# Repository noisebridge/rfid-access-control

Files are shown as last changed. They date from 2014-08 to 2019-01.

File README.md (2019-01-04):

RFID access control
-------------------



Access control system used within the [Noisebridge] hacker space.

   - RFID door terminal
      * [Firmware](software/firmware/README.md)
      * [PCB](hardware/terminal/README.md)
      * [3D printed case](hardware/terminal-case/README.md)
   - [Multi RS232 serial interface with RJ45](hardware/multi-interface/README.md)
   - [Earl: Central access control software](software/earl/README.md)

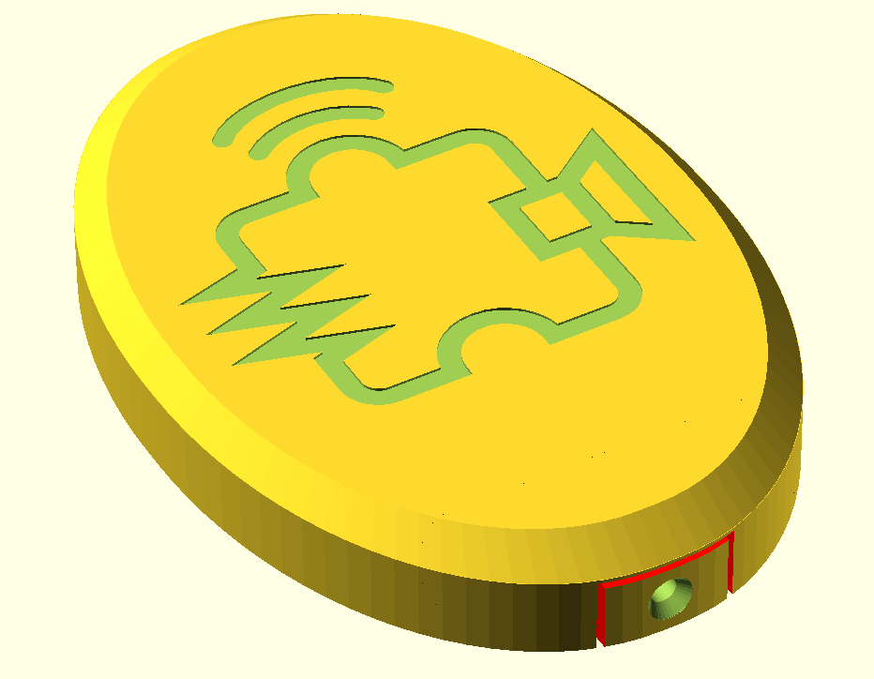
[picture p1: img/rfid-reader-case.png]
RFID reader


[case-image]: https://github.com/hzeller/rfid-access-control/raw/master/img/rfid-reader-case.png
[Noisebridge]: https://noisebridge.net/

## License

All code and PCB designs are released under the GNU General Public License V2, found in LICENSE

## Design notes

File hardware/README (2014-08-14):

Case
   - a case to mount the RFID reader on the wall.

Boards
  - terminal board with RFID-RC522, providing a serial interface and potentially
    local switching
  - interface board on 'server' side, interfacing the Raspberry Pi or Beaglebone
    with the physical world of serial interfaces an relay switching.

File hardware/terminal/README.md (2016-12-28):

Terminal PCB
============

The Access terminal mounted at the outside of the door. Typically connecting the
RFID reader (via SPI interface), but also a 4x3 keypad (or just simple door-bell
button) and an LCD can be connected. If wanted, even an electric strike via
some external H-bridge.

This is based on an Atmega8 because I had a bunch lying around, but the DIL
version is bulky and ideally, I'd like to have a bit more IO pins, such as
for a 4th row of the keypad or separate LED outputs; future versions might
change to atmega168 (currently the best Atmel-IO bang for the buck).

This board provides the necessary breakouts to connect the peripherals to an
Atmega8 and holds the MAX232 compatible line driver.
The software in `../../software/firmware` makes it useful.

For a housing of this board and the RFID reader, have a look at
`../terminal-case`

Feature overview
----------------

   - Sized so that it can be sandwiched with a RFID-RC522 board (40mmx60mm),
     including the same mounting holes.
   - Communication via RS232, using standard RJ45 plug.
   - Separate 4-pin header to connect without RJ45
   - In-circuit programming header.
   - Uses Atmega8 in PDIP cases, mostly because I had a bunch lying around :)
   - Allows to connect RFID-RC522, 4x3 keypad, HD44780 LCD, RGB-LED,
     speaker-buzzer. All supported by firmware.
   - Uses a [SP3232E][sp3232-spec], essentially a MAX232 compatible chip
     for 3.3V supply voltage and only 100nF capcitors needed.
   - Uses the SP3232E charge pump to get the negative voltage needed to drive
     LCD contrast.
   - Little 'breadboard area' for quick hacks.

Serial connection with RJ45
---------------------------

Pinout of RJ45 is a somewhat 'standard' way to connect an RJ45 with RS232
and is used in [Various][rj45-terminal-1] [router][rj45-terminal-2]
terminal connections (But note to whoever came up with this first probably 20
years ago: **bad choice**! Pin 3 and 6 are twisted together in an ethernet
cable, so this just optimized crosstalk between RX and TX...).

We also power the terminal circuit via the RJ45. We use the fact that the
lines `DTR` and `RTS` can always be set to +12V safely (within RS232 voltage
range) from the host (=[Data Terminal Equipment; DTE][DTE]). We use that to
provide power to our terminal (for any other endpoint with RJ45, this set-up
would look like a benign 'always ready' flow control signal; so does not damage
equipment). With two lines providing power, it should be possible to power
smallish loads such as an electric strike even over a longer line without too
much voltage drop.

The following list is the RJ45 connections from view of the terminal,
the [DCE side][DCE].
The *Line* in the following list represents the corresponding RJ45 pin.
Also as reference gives the [9-pin Sub-D connector (DB9)][db9-pinout]
equivalent connection on a 'standard' connector.
NB: Depending on the wiring (T568A or T568B), the color of Line-3 is either
striped orange or green, the Line-6 solid orange or green.

   - Line 1: Not connected (usually: DCE:RTS (out) / DTE:CTS (in)) *DB9-8*
   - Line 2: Not connected (usually: DCE:DTR (out) / DTE:DSR (in)) *DB9-1*
   - Line 3: **TxD**  (on host DTE:RxD) *DB9-2* (orange or green striped)
   - Line 4: **GND** (on host DTE:RI, 'Ring indicator') *DB9-5* (DB9-9). (Blue solid).
   - Line 5: **GND** (GND) *DB9-5* (Blue striped).
   - Line 6: **RxD** (on host DTE:TxD) *DB9-3*  (orange or green solid)
   - Line 7: **12V** supply in (usually: DCE:DSR (in) / DTE:DTR (out), DB9-4; but not connected there, just constantly powered. (Brown striped).
   - Line 8: **12V** supply in (usually: DCE:CTS (in) / DTE:RTS (out), DB9-7; powered, dito) (Brown solid).

(Let's see how well RS232 works, if long lines create trouble, we might consider
RS422 physical).

Hacking DB9 to RJ45 connector
------------------------------
If you want to have a standard DB9-female to RJ45 connector work with
this terminal, you need to hack it: open it up, and *disconnect* the cables
that go to **DB4** and **DB7** and instead connect them to an external 12V
power supply, with ground connected to **DB5** (ideally, you'd provide some
current limiting like 500mA to the 12V line; so if things go wrong, not
catastrophically so).

Double check on the RJ45 connector, that line 4 and 5 are on ground,
Line 7 and 8 on +12V.

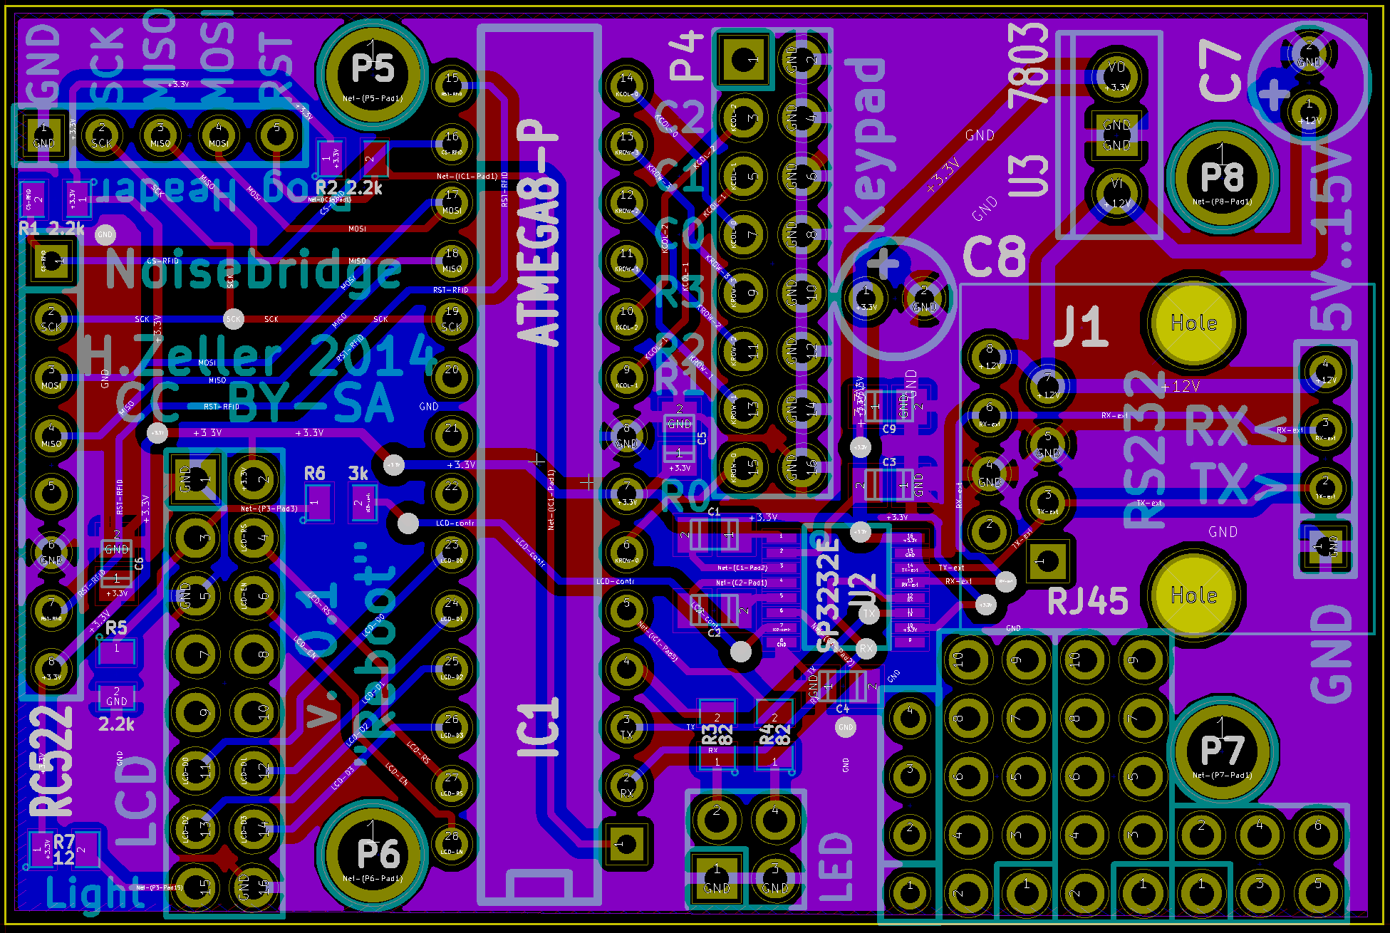
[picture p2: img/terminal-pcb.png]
PCB


Assembly
--------
Watch out in this version of the board, the [LD1117] LDO has to be soldered
in differently than the board suggests.

Unfortunately, it has a different pintout than other voltage regulators, this
is why it slipped in. Instead of [`Vin`, `GND`, `Vout`], it is
[`GND`, `Vout`, `Vin`]. So you need to solder in some lead-twisting :)

Tip for the RC522 reader. Depending on how you sandwich it, the chrystal oscillator it
has on top pokes out to the front; it might make sense to resolder it and put on the back
of the board.

TODO
----
TODOs for future versions; learning from previous board

   - Switch to atmega168 with less bulky 32 TQFP and 4 more IO pins.
   - Fix pin-out of LDO (also, switch to ceramic capacitors for less
     board height)
   - In general optimize board for best stacking, e.g. avoid collision with
     the crystal on the RFID board.
   - Provide an extra fourth column for keypad.
   - separate connector for 4st row, 4th column for an optional door-bell.
   - Silkscreen label all the pins for RC522 to minimize confusion which way
     to stack.
   - separate out RGB LEDs from LCD (when more IO available)
   - Maybe provide a reverse 8x2 connector for LCD (some LCDs are better
     connected from the reverse side)
   - Provide additional 16x1 connector to simply connect these LCD types.
   - Directly mount RGB LED on bord for less mouting hassle
   - Separate RX/TX connector on TTL side for easier testing.
   - Add space for 754410 to possibly directly drive door-strikes.
   - Add space for extra transistor to amplify speaker output.
   - Add space for little buzzer on-board.
   - Input for a reed switch to detect open doors ?

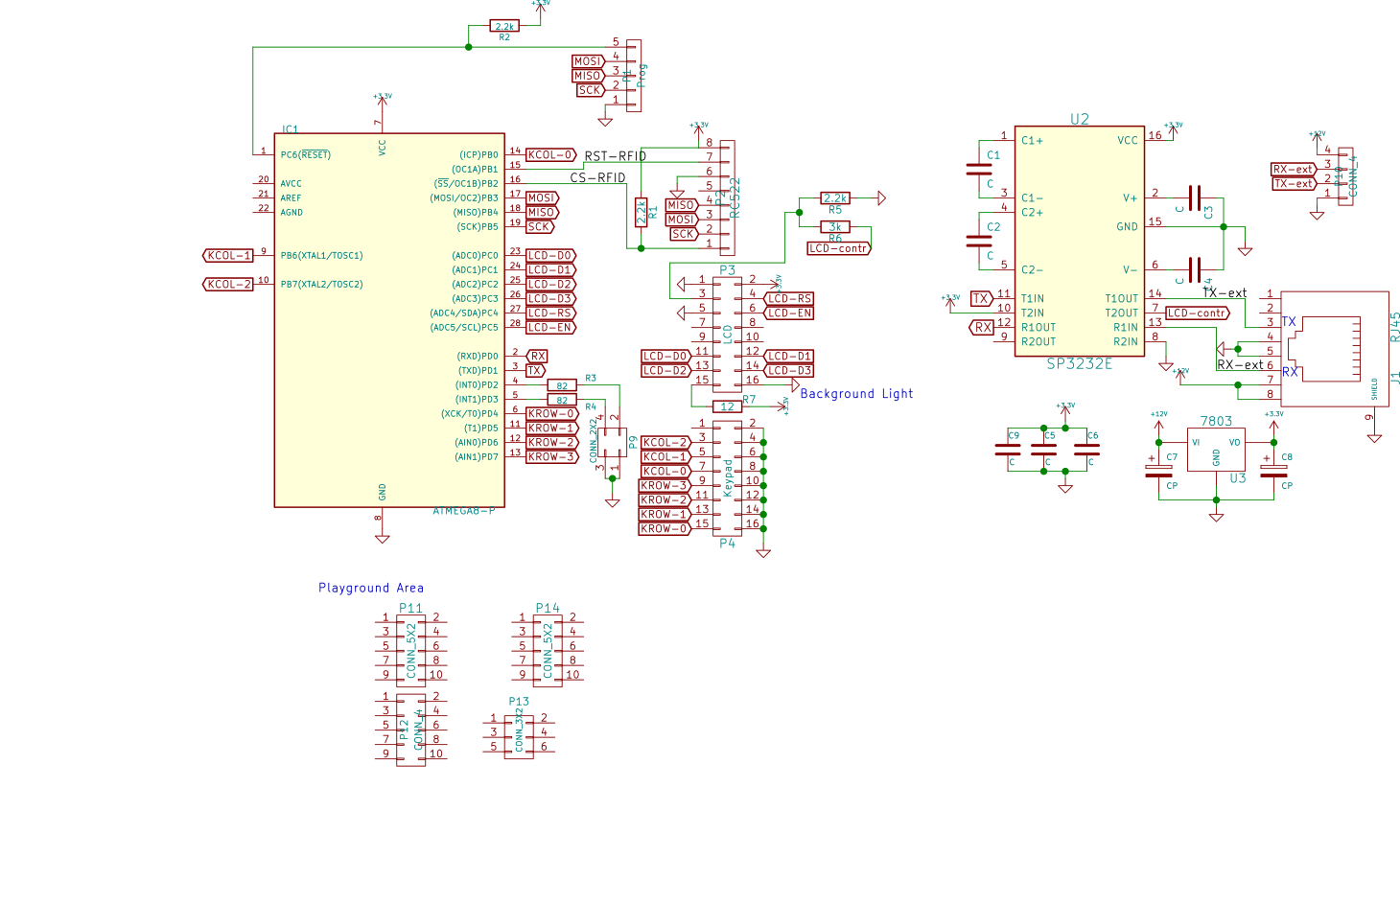
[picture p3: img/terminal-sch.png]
Schematic


[pcb]: ../../img/terminal-pcb.png
[schematic]: ../../img/terminal-sch.png
[sp3232-spec]: http://www.exar.com/common/content/document.ashx?id=619
[rj45-terminal-1]: http://www.allpinouts.org/index.php/Cisco_Console_RJ45_to_DB9_Pin
[rj45-terminal-2]: http://kb.juniper.net/InfoCenter/index?page=content&id=KB13272
[db9-pinout]: http://www.db9-pinout.com/
[DTE]: http://en.wikipedia.org/wiki/Data_terminal_equipment
[DCE]: http://en.wikipedia.org/wiki/Data_circuit-terminating_equipment
[LD1117]: http://www.st.com/web/en/resource/technical/document/datasheet/CD00000544.pdf

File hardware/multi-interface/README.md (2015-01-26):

Multi serial line driver RJ45
=============================

Features
--------
   - 4 interfaces with RJ45 plugs (uses a combined 4-block of RJ45 I found in
     an old switch. Standard distance would need to pull these apart 50 thou/mil)
   - TTL compatible with 3.3V, so can interface with Rasberry Pi or
     Beaglebone Black.
   - Creates RS232 line voltages from a single 3.3V supply.
   - Uses a [SP3232E][sp3232-spec], essentially a MAX232 compatible chip
     for 3.3V supply voltage and only 100nF capcitors needed.
   - Allows to power external terminals on Line 7 and 8 (see `../terminal` for
     details)
   - FYI M3 mounting holes are 18mmx64mm apart.

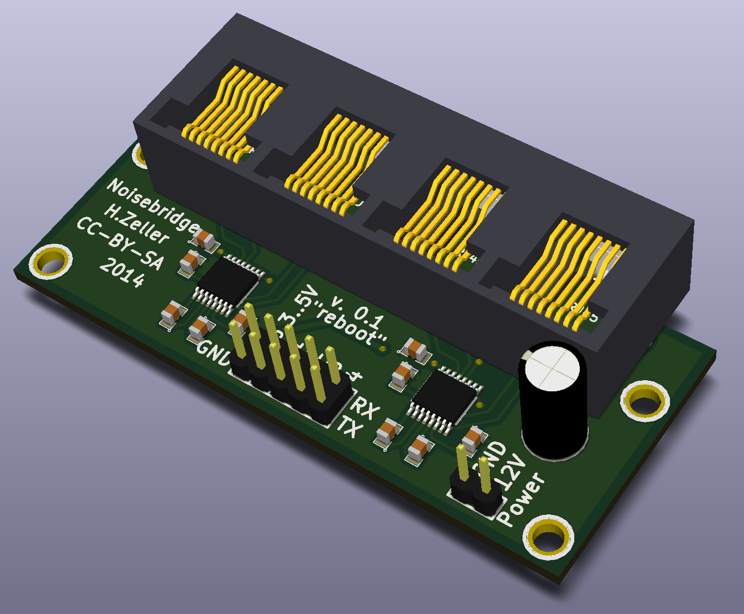
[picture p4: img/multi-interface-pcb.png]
PCB


TODO
----
Learnings from first board, possibly add to second revision

   - It would be useful to have a four line voltage/ground connector, directly
      compatible with the corresponding 4-pin connector on the terminal side.
   - Silk-screen marking RX/TX
   - 3-Pin connector for 12v: [GND-12v-GND] to allow turn-agnostic plug.
   - Possibe protection circuit: reverse polarity protection diode; PTC fuse
   - optional 12V power LED ? Maybe optional 3.3V power LED
   - RX/TX LEDs. Check connection of RJ45 plugs, some have built-in LEDs
     (usually to indicate Ethernet 100Mbps/1Gbps), would be cool to re-use
     these. Also optional space for discrete diodes.
   - All LEDs: also provide pads on the bottom of the board if that is the
     part visible.
    
[pcb]: https://github.com/hzeller/rfid-access-control/raw/master/img/multi-interface-pcb.png
[sp3232-spec]: http://www.exar.com/common/content/document.ashx?id=619

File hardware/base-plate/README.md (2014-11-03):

Base-plate mount
----------------

   - Laser-cut acrylic for the base plates
   - 3D printed standoffs for various boards (openSCAD file, you can create
     the STL using the Makefile)
   - Drill guides in postscript (TODO: move to laser-cut once settled)

Just add countersink screws :)

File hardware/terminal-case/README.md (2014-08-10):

The case for the RFID reader.
=============================

   - Mounting holes for the wall on the base-plate, invisible from top.
   - Cleat system allows for single-screw fixing of outer shell to wall.
   - Cabeling behind the board
   - Noisebridge Logo lends itself to a nice RFID-logo modification :)
   - The Logo is a bit recessed, so that it can be scrape-filled with a bit
     of black paint.

Case

The case comes in two pieces, the base and the top case. The base is mounted
permanently to the wall (with three drywall-screws), the top case slides on
top of it and is held in place almost invisible with a single mounting screw
at the bottom.

Even without that mounting screw, gravity holds the case in place.
The mounting screw pulls down the inner assembly and thus firmly pulls it towards
the wall.
Removing that screw allows to slide the case off easily moving slightly upwards.

This 'xray' view reveals the 'french cleat' system that does the magic.
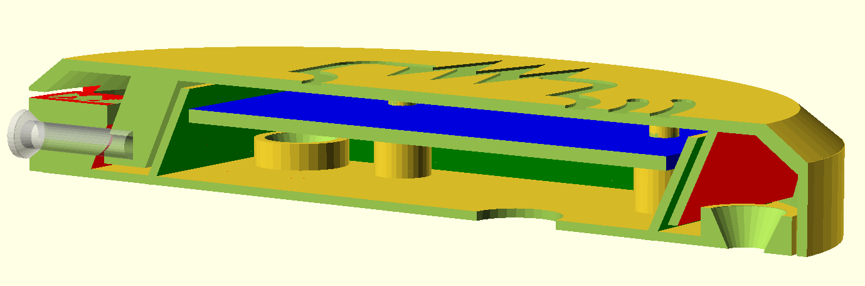
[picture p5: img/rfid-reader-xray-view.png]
On the inside


Hacking
-------
The case is written in OpenSCAD. The code could use a run of cleanup now that
it is clear how the result should look like :)

To get he logo, you have to first generate the dxf file from svg:

     make Noisebridge-logo.dxf

[case-image]: https://github.com/hzeller/rfid-access-control/raw/master/img/rfid-reader-case.png
[xray]: https://github.com/hzeller/rfid-access-control/raw/master/img/rfid-reader-xray-view.png

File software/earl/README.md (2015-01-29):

<!-- -*- mode: markdown; indent-tabs-mode: nil; -*- -->
Earl - Host Software
====================

Software running on the host computer.
Running on an Raspberry Pi to access some GPIO pins and multiple serial
interfaces.

Language
--------
Written in Go. Mostly to learn a new language. Also it has the simplicity of
Python without the ugliness of Python.

The previous version of this software was called `baron`. This being the next
version, it is called `earl`.

Compile
-------
(TODO: mostly placeholder. To be filled with correct information)
To get going, install go if you haven't already:

     sudo aptitude install golang

Set your environment variable `GOPATH` to some directory where you would
like to have your [go workspace][golang-gopath]. That is the scratch space
where go puts build artifacts and dependent libraries.

     export GOPATH=~/go-root    # Good idea to put that in your ~/.bashrc
     mkdir $GOPATH

(Also, on the Raspberry Pi, you want to set the environment variable `GOARM=5`,
otherwise binaries don't run.)

Ok, back to the `rfid-access-control/software/earl` directory.

     go get       # Only do this the first time. Get needed serial library.
     
     make         # Builds binary, runs tests
     
     # Installing. Like everything running as root, you first want to see what
     # the following command is doing. So let's do a dry-run
     make -n install

     # Alright, ready for the real thing
     sudo make install # install binary and init.d script

Hacking
-------
Adding some code that deals with a serial terminal is simple. The low-level
handling of terminals is taken care of for you. In order to
interact with a terminal, you need to implement a `TerminalEventHandler` to
receive events such as key-presses and RFID tokens. You'll get passed a
`Terminal` API that allows you to interact with the terminal (switching on LEDs
or writing to the LCD display and such).

Having said that, you probably don't have to implement anything for a new door
type as `AccessHandler` probably already does what you need.

The `Authenticator` is the interface that implements the API to authenticate
users. Also user change operations are implemented (which in itself it requires
to be authenticated). The implementation, the `FileBasedAuthenticator` is storing
its state in a simple (possibly hand-editable) flat CSV file.

The interesting stuff interacting with the access terminals is implemented
in `accesshandler.go`. In `authenticator.go`, there is the ACL file handling.
The LCD frontend stuff is implemented in `uicontrolhandler.go`.

Interfaces
----------
** Serial interface
(TODO: describe serial interfaces connected. Currently: the build-in /dev/AMA0
and two USB serial adapters. Describe that it does not matter where to connect
any terminal, they find their place)

** Relays
(TODO: describe connection to GPIO pins)

** RPi On-board Serial Interface

If you want to use the `/dev/AMA0` serial interface of the Raspberry Pi, make sure
to comment out the getty line in `/etc/inittab` that grabs that interface.
Otherwise things don't work smoothly :)

Features
--------
Features so far.

   - Talk the serial interface provided by the access terminal and
     its firmware (see these directories).
   - Should read gate PIN numbers from a file as read by previous access
     control system Baron ( https://github.com/noisebridge/noisebridge-baron )
   - Have another file with RFID numbers. Also this contains flags
     saying which user can add other users (Members can)
   - Both files should be re-loaded whenver they change externally
     (i.e. edit)
   - Multiple terminals can be connected to various ttys whose paths are
     given on the commandline. Internally, the program queries the name of the
     terminal to associate file-descriptor with physical terminal (thus,
     swapping the serial lines is not a problem). There is a handler for each
     of the named terminals; each of them might do different things.
   - There are 2 relay contacts connected to the Raspberry Pi that
     can be used to open gates. This happens via GPIO pins via the
     file `/sys/...` interface as we don't need speed.
   - There are 4 terminals to be handled by this software
     (probably later more)
     Each of them does a little bit different things, they should be implemented
     in a simple way (so: someone only needs to implement a handler), with the
     complicated stuff (serial line and such) handled in the background.
     Note, each of these have a human readable name (see firmware help how to
     set it).
       - Downstairs gate. Reads PIN number or RFID. If match, gate is opened
         via one relay contact.
       - Upstairs door. Reads RFID. If match, upstairs gate is opened
         via other relay contact.
       - In-space terminal (probably inside next to
         the door). Has keypad, RFID reader and LCD display. Provides simple
         way to add new users, something like:
          1. show existing RFID card of Noisebridge member.
          2. ask to add user or update user.
          3. present user RFID card.
          4. new RFID card is added to the file (or time extended)
        User-interaction with keypad and LCD display.
        - TODO: allow to add temporary pins
        - TODO: provide a terminal interface
   - (_TBD_) Future: We might equip a terminal with an H-bridge to open the
     electric strike, thus relieving one of the relay contacts.
     That would be connected to the inside terminal at the door upstairs. The
     outside terminal receives an RFID request, and when it decides that this
     was ok, tells the _inside_ handler to open the strike. This needs to be
     handled in a thread-safe way as each terminal can only have one outstanding
     request at a time to avoid confusion. Initially: not needed.

[golang-gopath]: https://golang.org/doc/code.html#GOPATH

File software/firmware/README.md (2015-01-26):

Access Terminal Firmware
========================

Firmware to run on the external nodes, typically featuring an RFID-RC522 reader
and potentially other peripheral such as a Keypad or an LCD screen. Some
may have an H-Bridge to switch or buzz a door strike.

They interface with a serial interface with a simple protocol with the host.

Based on Atmega8 (because I had a bunch lying around). Running on 3.3V as
this is the voltage needed by the RFID reader.

Peripherals
-----------

### RFID-RC522

The reader to interface is the RFID-RC522; there are a bunch available everywhere
and they are cheap - in the order of $5. They interface via SPI with the
microcontroller. Uses https://github.com/miguelbalboa/rfid to interface with
the RC522 board, but hacked to not depend on Arduino libraries.

It only uses a tiny subset of that library: to read the UID (which could
probably be simplified, because it is quite a chunk of code). But hey, it was
already there and I have 8kiB to waste (also, I tell the linker to throw out
unused stuff as much as possible).

Uses the SPI port and part of port B.

This is how a typical board looks like

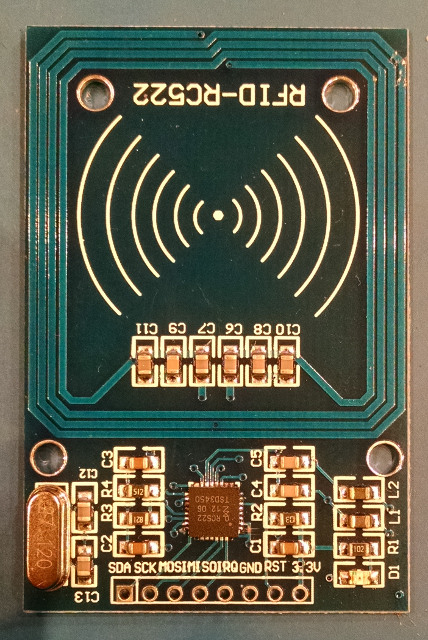
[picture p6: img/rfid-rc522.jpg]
RFID-board


Connections from board to Atmega8
   - **SDA** _(-CS)_ to **PB2**   (Pin 16 on PDIP Atmega8)
       (and good to have a pull-up to 3.3V so that in-circuit programming works
        reliably)
   - **SCK** to **SCK**   (Pin 19 on PDIP Atmega8)
   - **MOSI** to **MOSI** (Pin 17 on PDIP Atmega8)
   - **MISO** to **MISO** (Pin 18 on PDIP Atmega8)
   - **IRQ** (not connected)
   - **GND** to **GND**
   - **RST** _(-Reset)_ to **PB1**   (Pin 15 on PDIP Atmega8)
   - **3.3V** to **3.3V**

### LCD

Compile time option `-DFEATURE_LCD=1`

If this terminal should have an LCD to display messages or interact wit the
user, then these are connected to PC0..PC5 to the microcontroller.

Unfortunately, many displays only work with 5V to display proper contrast.
With 3.3V, the you need to connect the contrast input to a _negative_ voltage.
In the board design, this is achieved by connecting it to one of the charge-pump
outputs of the RS232 level shifter.

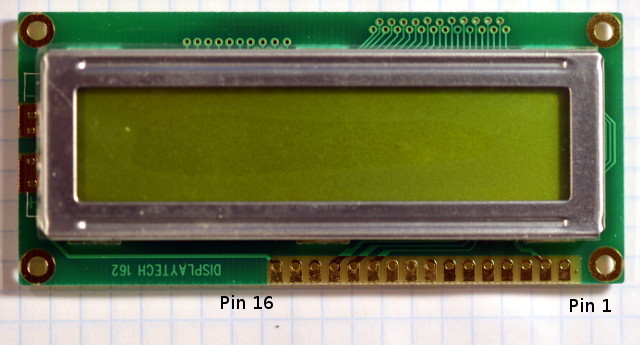
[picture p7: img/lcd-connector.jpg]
LCD connector


The LCD typically has 14 or 16 connector pins. Connections from LCD to Atmega8
   - **LCD 1** _(GND)_ to **GND**
   - **LCD 2** _(VCC)_ to **3.3V**
   - **LCD 3** _(contrast)_ to ~-1.5V negative voltage.
   - **LCD 4** _(RS)_ to **PC4** (Pin 27 on PDIP Atmega8)
   - **LCD 5** _(R/-W)_ to *GND** _We only write to the display,
      so we set this pin to GND_
   - **LCD 6** _(Clock or Enable)_ to **PC5** (Pin 28 on PDIP Atmega8)
   - LCD 7, 8, 9, 10 are _not connected_
   - **LCD 11** _(Data 4)_ to **PC0** (Pin 23 on PDIP Atmega8)
   - **LCD 12** _(Data 5)_ to **PC1** (Pin 24 on PDIP Atmega8)
   - **LCD 13** _(Data 6)_ to **PC2** (Pin 25 on PDIP Atmega8)
   - **LCD 14** _(Data 7)_ to **PC3** (Pin 26 on PDIP Atmega8)
   - If availble: LCD 15 and LCD 16 are for background light.

### RGB LED

Compile time option `-DFEATURE_LCD=0`

If the LCD is not chosen, a RGB LED with a common anode can be controlled
instead. Output bits are somewhat random, so here documented for convenience:

  - **Common Anode** to **3.3V** (LCD-2 connector)
  - **RED cathode** to **PC5** (Pin 23 on PDIP Atmega8; LCD-6 connector)
  - **GREEN cathode** to **PC4** (Pin 27 on PDIP Atmega8; LCD-4 connector)
  - **BLUE cathode** to **PC1** (Pin 24 on PDIP Atmega8; LCD-12 connector)

### Keypad

Can read a standard 3 column x 4 row phone style keypad and output its debounced
values on the serial line.

The keypards typically come with four 'row' connectors and three 'column'
connectors, 7 pins total.
   - **Row 0** to **PD4** (Pin 6 on PDIP Atmega8)
   - **Row 1** to **PD5** (Pin 11 on PDIP Atmega8)
   - **Row 2** to **PD6** (Pin 12 on PDIP Atmega8)
   - **Row 3** to **PD7** (Pin 13 on PDIP Atmega8)
   - **Col 0** to **PB0** (Pin 14 on PDIP Atmega8)
   - **Col 1** to **PB6** (Pin 9 on PDIP Atmega8)
   - **Col 2** to **PB7** (Pin 10 on PDIP Atmega8)

### Tone generation

For keyboard beeps and server-controlled beep tones, connect

   - **Speaker** to **PD2**

Serial Protocol
---------------
Simple line based protocol (the previous generation of the Noisebridge
access terminal was character based, but this doesn't work well anymore with
increased functionality).

Each value **sent** from the terminal comes as full line
(or lines in case of the help command). All lines end with `<CR><LF>`
because that displays well out of the box with any terminal emulator
(e.g. minicom), without too much configuration.
Lines **received** from the host are accepted with `<CR>` or `<LF>` or both.
Lines received are clipped if too long.

We only use RX and TX, so hardware flow control needs to be switched off. Default
communication parameters are **9600 8N1**, but you can set the baud-rate
later and store in EEPROM or compile in a different speed.

### Terminal -> Host

#### RFID

Whenever a new RFID card is seen, its ID is sent to the host:

     Ixx yyyyyyyy<CR><LF>

(Example: `I07 c41abefa24238d`)
With xx being the number of bytes (RFID IDs come in 4, 7 and 10 bytes). All
numbers are in hex, so values for length would be one of `04`, `07`, `0a`,
followed by the actual bytes as hex-string.

While the card is in range, this line is repeated every couple of 100ms.

#### Keypad
Each Key pressed on the phonepad is transmitted with a single line

     K*<CR><LF>

The star representing the key in this case.

### Host -> Terminal

The terminal also responds to one-line commands from the host.
They are one-letter commands, followed by parameters and end
with a `<CR>` or `<LF>` or both. Commands with upper-case letters modify
the state of the system, lower-case letters just read information.

Type `?` (+ newline) to get help over the serial line.

     # The following, lower-case letters read state, don't modify
     ?       : Prints help.
     n       : Read name of terminal as set with 'N'.
     s       : Read stats.
     r       : Show MFRC522 registers.
     e<msg>  : Just echo back given message. Useful for line-reliability test.
               (Use with line length ~ <= 30 characters).

     # Commands with upper-case letters modify the state.
     M<r><msg>
             : Write a message to the LCD screen. <r> is a single digit
               giving the row to print in, can be 0 or 1).
               The following example writes 'Hello World' into the second line:

                 M1Hello World

     R       : Reset RFID reader (Mostly debug; should typically not be necessary
               except after physical connection reconnect of its SPI bus).
               
     N<name> : Persistently set the name of this terminal. To avoid
               accidentally setting this, it prompts you to be called twice.
               
     B<baud> : Set baudrate. Accepts one of the common baudrate
               values { 300, 600, 1200, 2400, 4800, 9600, 19200, 38400 }.
               This changes the baudrate when this command returns.
               If it is changed, it is _not_ stored in EEPROM, so that you
               can test the new setting with changed parameters in your terminal
               program. If you can't communicate anymore, a power-cycle brings
               the terminal back to the previous baud-rate.
               If you are already at the baud-rate you specify (which obviously
               means that you _can_ communicate), it is persisted in EEPROM:
               Next time the terminal comes up, it will use this baudrate.
               So essentially: similar to 'N', you have to give this command
               twice to actually persist a new baudrate.
               
     L[<R|G|B>]:  Set (combination of) LED Red/Green/Blue. Just L without
                parameter switches LEDs off.

     T<L|H>[<ms>] Low or High tone for given time (default 250ms). Simple
                user interaction.

     F<K><1|0> Set flag. 'K'=Keypad click.
    
     (TODO: specialized command to buzz or silent open, using two outputs
      to connect H-bridge)

Each command is acknowledged with exactly one line prefixed with the letter of
the command, *or* on error in that command, the returned line starts with `E`.
Lines starting with `#` are informal for user interaction (e.g. startup screen
or help output) and should just be skipped by programmatic interfaces.
Makes interfacing the protocol simple.

Compiling
---------
To compile, you need the avr toolchain installed:

     sudo aptitude install gcc-avr avr-libc avrdude

... and a programmer.

    make fuse   # will set the right fuses in the programmer (first time)
    make flash  # compiles code and flashes it to the system.

If your avrdude is not connected to `/dev/ttyUSB0`, you can set the actual
device via environment variable:

    AVRDUDE_DEVICE=/dev/ttyUSB1 make flash

See Makefile for details.

The first time, you might want to initialize the eeprom to sensible values.

    make eeprom-flash

Sets the terminal name to `terminal` and sets the baud-rate to 9600.
(Both values you can change later via the serial interface, using the `N` and
`B` command)

Testing line speed
------------------
To test if the line speed is working for the given environment (long cable,
noisy line etc.) you can use the `e`-cho command to see if you get the same
data out as you get in. Let's generate some test-data and compare input and
output.

     $ i=1 ; while [ $i -lt 5000 ] ; do echo -en "eTest Echo $i\r\n" ; i=$[i+1]; done > /tmp/a.txt
     $ cat /tmp/a.txt | socat -b 256 STDIO /dev/ttyUSB1,raw,echo=0,b9600 > /tmp/b.txt
     $ diff /tmp/a.txt /tmp/b.txt

NB: Make sure to send each line with `<CR><LF>` (\r\n), as it is echoed with this
line-ending, indepenent of the input line-ending.
If you only send one character (e.g. \n), then the echo command would have to
write more data out than comes in - which would run out of TX buffer on writing.

While experimenting, just use the `B<baud>` command to change to different
speeds (With a short cable, it works fine up to 38400, but with long lines
I'd measure the best speed that doesn't produce any errors and then use
half that). (TODO: report back what actually worked for the 10+meter cable
at Noisebridge)

Setting up a new Terminal
-------------------------
A checklist:

   - Choose default baudrate and compile-time defines in Makefile.

   - First time set-up of Atmega8: `make fuse`

   - Writing EEPROM settings (default name and baudrate): `make eeprom-flash`
     (you typically want to do that only once, later these settings can be
     changed via the protocol).

   - General compiling and flashing: `make flash`

   - Connect with a terminal program (e.g. `minicom`), test
     connected LEDs, buzzer, LCD etc. using the terminal interface and that
     RFID reader and/or keypad return data. Make sure to switch off hardware
     and software flow control (`CTR-A O`, then `serial port setup` in minicom).

   - Optional: Test line speed as described above to optimize for your setup.

     Note, inputs from RFID or keypad are fine with lower speeds
     (300 or 600 baud), thus more resilient to long cables; if you have an
     LCD connected, you might want more for more 'snappy' user-interaction.

   - Choose a name for the terminal to be used in your system. That way,
     the host-software can distinguish the terminals no matter what serial
     line they are connected to. Use descriptive names, e.g. _'Gate Downstairs'_
     or _'Elevator-3rd-floor'_. The command to use is `N<name>`, see serial
     protocol description; you need to set it _twice_ to store permanently.
     Check the current name with the lowercase `n` command.

   - Optionally check the contents of the eeprom if you are
     curious: `make read-eeprom`

     The first 32 bytes contain the name, followed by the baudrate.

Hacking in progress:

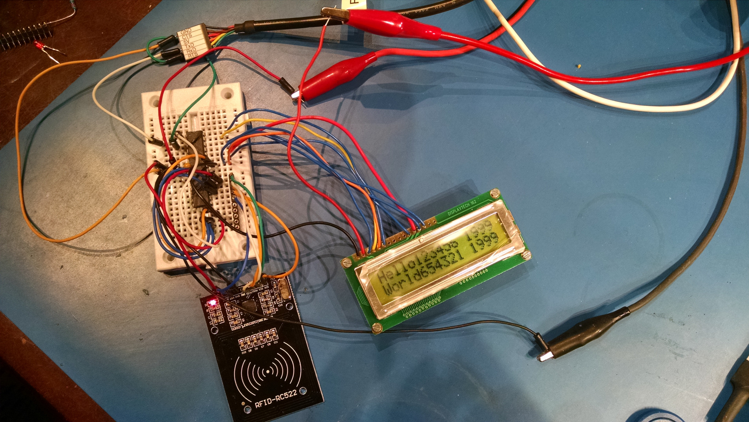
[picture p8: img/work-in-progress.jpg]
Work in progress


[work]: https://github.com/hzeller/rfid-access-control/raw/master/img/work-in-progress.jpg
[rfid-board]: https://github.com/hzeller/rfid-access-control/raw/master/img/rfid-rc522.jpg
[lcd]: https://github.com/hzeller/rfid-access-control/raw/master/img/lcd-connector.jpg

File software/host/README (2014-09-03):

Software running on the host computer. Currently expected to be Raspberry Pi.

Rough Spec

   - Should read old Baron ( https://github.com/noisebridge/noisebridge-baron )
     file with PIN numbers.
   - Have another file with RFID numbers. Also this contains flags saying which
     user can add other users.
   - Both files should be re-loaded whenver they change externally (i.e. edit)
   - Multiple terminals can be connected to various ttys whose paths come
     on the commandline. Internally, the program queries the name of the
     terminal to associate file-descriptor with physical terminal (thus,
     mangeling the serial lines is not a problem).
   - There are 2 relay contacts connected to the Raspberry Pi that can be used
     to open gates. This happens via GPIO pins.
   - There are 4 terminals to be handled by this software (probably later more)
     Each of them does a little bit different things, they should be implemented
     in a simple way (so: someone only needs to implement a handler), with the
     complicated stuff (serial line and such) handled in the background.
       - Downstairs gate. Reads PIN number. If match, gate is opened via one
         relay contact.
       - Upstairs door. Reads RFID. If match, upstairs gate is opened via other
         relay contact.
       - In-space terminal (probably inside next to the door). Has keypad,
         RFID reader and LCD display. Provides simple way to add new users:
	 (1) show existing RFID card of 'deciding member'
	 (2) ask to add user
	 (3) present new RFID card.
	 (4) new RFID card is added to the file.
	 User-interaction with keypad and LCD display.
       - Elevator door. Later.
   - Future: We might equip a terminal with an H-bridge to open the electric
     strike, thus relieving one of the relay contacts.
     That would be connected to the inside terminal at the door upstairs. The
     outside terminal receives an RFID request, and when it decides that this
     was ok, tells the _inside_ handler to open the strike. This needs to be
     handled in a thread-safe way as each terminal can only have one outstanding
     request at a time to avoid confusion. Initially: not needed.

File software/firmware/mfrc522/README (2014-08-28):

This contains the MF-RC522 library to be found on

   https://github.com/miguelbalboa/rfid

License: Public domain.

Copied over to this project to do allow simple one-stop compile. Also
some local changes:
   - Don't depend on Arduino libraries.
   - Consistent code indentation.

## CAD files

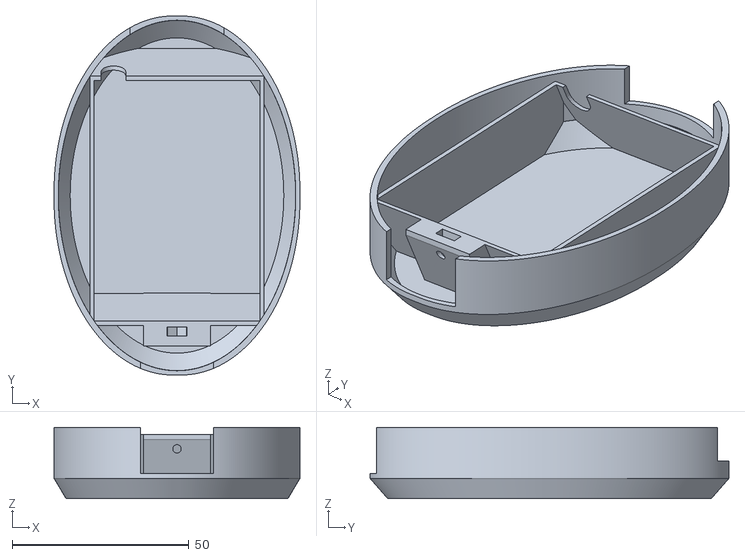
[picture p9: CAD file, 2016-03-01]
hardware/terminal-case/rfid-cover-top.stl
69.7 x 101.7 x 20.1

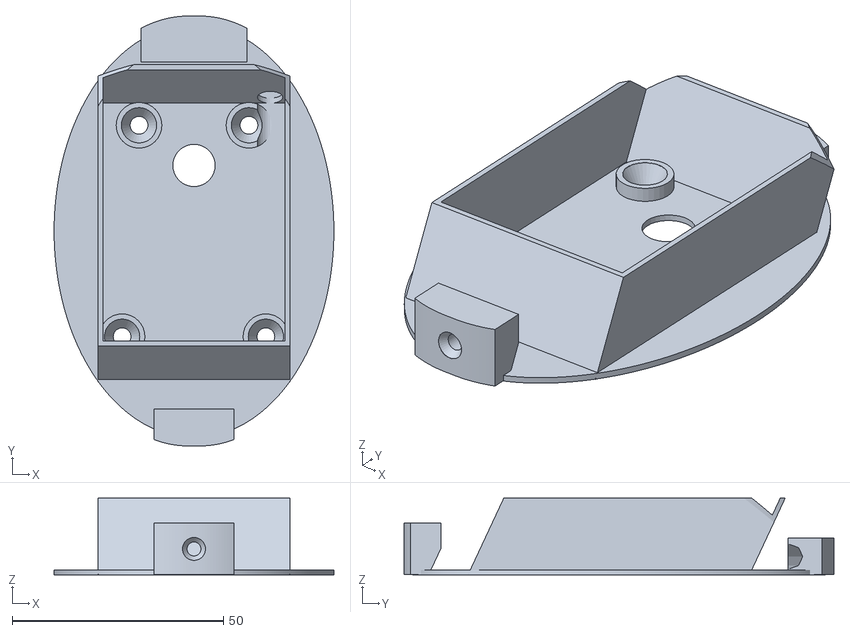
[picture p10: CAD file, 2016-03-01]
hardware/terminal-case/rfid-cover-base.stl
66.2 x 101.7 x 18.2

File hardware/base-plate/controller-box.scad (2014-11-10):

$fn=24;
epsilon=0.05;
clearance=0.3;

drill_x = 113;
drill_y = 31;

border=1.5;
drill_dia=3;
stud_dia=2*drill_dia;
nut_thick=2;        // The nut we slide in sideways
nut_dia=5;
bolt_top_flap=0.4;  // flap thickness covering up screw.

lcd_w=103 + clearance;
lcd_h=29.2 + clearance;
lcd_t=9.4;  // thickness
lcd_dx=2.3;
lcd_dy=(drill_y - lcd_h)/2;

module lcd() {
    translate([lcd_dx, lcd_dy, -epsilon]) {
	cube([lcd_w, lcd_h, lcd_t]);
	translate([0, 0, lcd_t-epsilon]) cube([lcd_w, lcd_h, 2]);
    }
}

module block() {
    translate([-stud_dia/2,-stud_dia/2,0]) {
	difference() {
	    cube([drill_x+stud_dia, drill_y+stud_dia, lcd_t]);
	    translate([border,border,-epsilon]) cube([drill_x+stud_dia-2*border, drill_y+stud_dia-2*border, lcd_t-border]);
	}
    }
    board_studs();
}

module bolt() {
    translate([0,0,lcd_t/2]) cylinder(r=nut_dia/2, h=nut_thick);
}

// Stud around drill.
module drill_stud() {
    difference() {
	cylinder(r=stud_dia/2, h=lcd_t);
	bolt();
    }
}

// The actual drill. Applied at the end.
module drill(angle=0) {
    translate([0,0,-epsilon]) cylinder(r=drill_dia/2, h=lcd_t - bolt_top_flap);
    // A slot to slide in the 
    rotate([0,0,angle]) translate([0,-nut_dia/2,lcd_t/2]) cube([2*stud_dia,nut_dia,nut_thick]);
}

module board_studs() {
    translate([0, 0]) drill_stud();
    translate([drill_x, 0]) drill_stud();
    translate([drill_x, drill_y]) drill_stud();
    translate([0, drill_y]) drill_stud();
}

module board_drill() {
    translate([0, 0]) drill(225);
    translate([drill_x, 0]) drill(315);
    translate([drill_x, drill_y]) drill(45);
    translate([0, drill_y]) drill(135);
}

module display_holder() {
    difference() {
	block();
	board_drill();
	lcd();
    }
}

rotate([180,0,0]) display_holder();
//display_holder();

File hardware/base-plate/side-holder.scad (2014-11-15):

$fn=8;
epsilon=0.05;
clearance=0.5;
acryl_thick=3 + clearance;
side_high=50;
side_thick=8.5;
side_len=53;
hold_thick=2;
screw_predrill=1.8;

module side(right=1) {
    difference() {
	union() {
	    // Base block.
	    cube([side_high, side_len + hold_thick, side_thick]);
	    // Block that covers where the acryl holder is

	    hull() {
		// Raised part to hold the acrylic
		translate([side_high-3*hold_thick, 0, side_thick+clearance]) cube([3 * hold_thick, side_len + hold_thick, hold_thick]);
		// Lower part, aligned with back wall
		translate([side_high-6*hold_thick, 0, side_thick-hold_thick]) cube([6 * hold_thick, side_len + hold_thick, hold_thick]);
	    }
	}
	
	// Acryl holder.
	translate([side_high - acryl_thick - hold_thick, right ? hold_thick : -epsilon, -epsilon]) cube([acryl_thick, side_len + 2*epsilon, side_thick+clearance+2*epsilon]);
    }
}

// The manual drills are not entirely accurate on the acrylic,
// so adapt to that :)
module left_bracket() {
    difference() {
	translate([0, -(side_len+hold_thick)]) side(right=1);
	// Drill holes.
	translate([-epsilon,-14.96,side_thick-3.869]) rotate([0, 90, 0]) cylinder(r=screw_predrill, h=side_high - 20);
	translate([-epsilon,-37.61,side_thick-4.755]) rotate([0, 90, 0]) cylinder(r=screw_predrill, h=side_high - 20);
    }
}

module right_bracket() {
    difference() {
	side(right=0);
	translate([-epsilon,12.83,side_thick-5.562]) rotate([0, 90, 0]) cylinder(r=screw_predrill, h=side_high - 20);
	translate([-epsilon,37.25,side_thick-3.95]) rotate([0, 90, 0]) cylinder(r=screw_predrill, h=side_high - 20);
    }
}

left_bracket();
translate([0, 10]) right_bracket();

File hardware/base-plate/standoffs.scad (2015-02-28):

// Standoffs for mounting parts.

epsilon=0.1;
standoff_height=3;
rpi_standoff_height=3.7;
$fn=24;

module drill(d=3.5,h=standoff_height) {
    translate([0,0,-2*h]) cylinder(r=d/2,h=4*h);
}

module relay(h=standoff_height) {
    width = 38.6;
    height = 50.6;
    drill_x_top = 33.5;
    drill_x_bot = drill_x_top - 1;
    drill_y = 44.7;
    translate([0,0,h/2]) difference() {
	cube([width, height, h], center=true);
	translate([0,-2,0]) cube([width-11.5, height-6, h+2*epsilon], center=true);
	//translate([0,-5,0]) cube([width-11, height, h+2*epsilon], center=true);
	cube([width-7, height-15, h+2*epsilon], center=true);
	translate([drill_x_top/2, drill_y/2, 0]) drill();
	translate([-drill_x_top/2, drill_y/2, 0]) drill();
	translate([drill_x_bot/2, -drill_y/2, 0]) drill();
	translate([-drill_x_bot/2, -drill_y/2, 0]) drill();
    }
}

module terminal(h=standoff_height) {
    translate([-6/2, -30/2, 0]) difference() {
	cube([6, 30, h]);
	translate([3, 3, 0]) drill();
	translate([3, 21, 0]) drill();
    }
}

module round_standoff(h=standoff_height, d=8) {
    difference() {
	cylinder(r=d/2, h=h);
	drill();
    }
}

module full_terminal() {
    // Terminal has two sides
    translate([-5, 0]) terminal();
    translate([5, 0]) terminal();
}

module standoff_collection(h=standoff_height) {
    // Some generic standoffs
    translate([25, 0]) round_standoff(h=h);
    translate([25, 20]) round_standoff(h=h);
    translate([25, -20]) round_standoff(h=h);
}

module sd_holder(h=rpi_standoff_height,m=3) {
    round_standoff(h=h);
    difference() {
	translate([-30.8+3.9-m/2,0.65- m/2,0])  cube([31.3+m,42.5+m,h]);
	translate([-30.8+3.9,    0.65,-epsilon]) cube([31.3,42.5,h+m]);
	drill();
    }
    translate([-30.8+3.9-m/2,4.65-m/2 + 38-15,0]) cube([31.3+m,15+m,0.4]);
}

// http://www.raspberrypi.org/wp-content/uploads/2012/12/Raspberry-Pi-Mounting-Hole-Template.png
module raspi(h=rpi_standoff_height) {
    difference() {
	cube([56,6,h]);
	translate([20, 1, -epsilon]) cube([56-20, 6, h+2*epsilon]);
    }
    translate([56-12.5, 5, 0]) round_standoff(h=h);
    translate([56-16, 0, 0]) cube([10, 3, h]);
    translate([56-3, 0, 0]) cube([3, 6, h]);

    // We need another standoff
    translate([0, 12, 0]) sd_holder();
}

module screw_terminal(w=38,d=10,h=8) {
    cube([w,d,h]);
}

module print_all() {
    relay();
    full_terminal();
    translate([-30, -35, 0]) raspi();
}

//print_all();
screw_terminal();

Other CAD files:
hardware/terminal-case/rfid-cover.scad

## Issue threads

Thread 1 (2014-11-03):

Automatic connect and re-connect terminals

hzeller, 2014-11-03:
Right now, we require that at startup, all devices are up; also it is not clear what happens on dis-connect and reconnect.
This needs to be robust
 - on startup, remember the interfaces to look at, but don't necessarily crash if they don't connect.
 - independently probe these interfaces when things are idle and check name; possibly re-wire channels
   if connections swap
 - Even better if we can get to know immediately when the state of the channel changes (maybe select on it works)

hzeller, 2015-02-02:
Fixed for a while now. Possible to disconnect, swap etc. Pretty robust now.

Closed 2015-02-02.

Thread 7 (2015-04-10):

produce binary that opens bottom gate / upper door

patrickod, 2015-04-10:
It'd be neat to have a binary that opens the gate and door such that it could be used to buzz people in remotely. This use case has come up recently so opening an issue to note it. Hopefully will get a chance to do this myself soon.

hzeller, 2015-04-10:
For the immediate case: Have a look in the home-directory pi@earl - there I
have a rough script that opens the toplevel door with 'manual' means
operating the GPIO pins directly. it needs to be adapted to take a
parameter to distinguish between upper and lower which essentially selects
the GPIO 8 or 7.

Having said that, something that remotely (_and_ securely) opens the gate
would be good. In general, there is the problem of authentication. RFID IDs
must be considered public knowledge as anyone can read them out if they
have access to the token. Often the ID is even printed on the token itself.

Our current (somewhat weak) security is based on the assumption that only
someone with sufficient hardware building capability is able to
radio-simulate the physical token towards the RFID reader if (s)he knows
the token ID. Having said that, such a person is probably welcome in a
Hackerspace :)

So to generate some authentication token, we would require reading in the
physical RFID somewhere, e.g. the door, and with that create an
'application token' of some kind that is valid for some time. It could be a
HMAC from the RFID key + ticket timeout, or, probably more secure w.r.t.
leaked earl keys, simply random string that is valid for a while and kept
in earls volatile memory, mapping that random key to the actual
authentication token including its expiry time.

This authentication token can be used for temporary door accesses like
these (and later to authenticate users on terminals etc.)

patrickod, 2015-04-10:
Opening the door via some remote API would be a neat extension in the
future.

or the moment however the use case I have in mind is: someone I know /
trust is at the door and unable to gain access to noisebridge. It'd be
neat to have a way to do this this remotely with access to earl via SSH.

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

--
Patrick O'Doherty
+1 (650) 701-7829

hzeller, 2015-04-10:
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

Yes, for that, the existing script is perfect.

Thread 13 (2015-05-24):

Web Interface

kevinjos, 2015-05-24:
The screen resolution and keypad of the dial pad make adding contact information challenging. Current usage dictates this information is needed for a key that does not expire. This limits the ability of users to adding new keys with a 30 day expirey from the dial interface.

I am working on the web interface to earl, piggybacking on the HTML APIServer, to allow users to add keys that do not expire. I forget exactly the flow discussed. This is what I have so far where User A is granting User B fulltimeuser privilage...

1. User A scans key to aquire onetime pass.
2. User A GETs earl's access page and POSTs onetime pass + user type + User B's contact information.
3. Dial pad key reader upstairs&inside listens for User B's key.
4. HTTP server responds with the status of the transaction (success/failure).

See https://github.com/kevinjos/rfid-access-control/tree/WebUI for details.

hzeller, 2015-05-26:
Something like that should work. Though there is a race condition after the POST and whoever randomly happens to swipe the key.

Maybe we can do something (even a little simpler) to what we already do when updating a user to extend the 30 days, because then we can do it with the one-pass solution and it might be simple to implement:
Current workflow:

  1) Member A swipes key, gets choice of [1] add user [2] update user
  2) Chooses [2] and swipes User B's key. User extended for another 30 days.

Now we can just add a little change here
 1) ... as usual.
 2) Chooses [2] and swipes User B's key. User extended for another 30 days. **A onetime password is shown to set the user-name**. That one-time is valid for a couple of minutes.
 3) a Web-browser accepts that one-time password and the information to be updated for that user.

So, in step 2 we just do the same as before, but just emit the additional one-time password. No race-conditions (as it is generated at the time the User A and User B interaction happens at the terminal). And possibly the simplest to implement as well.

kevinjos, 2015-05-27:
Sounds good. Do you see any problem with mapping the one-time password to the user when the upgrade choice is made? This would save the trouble of having to reenter the user id in the browser.

hzeller, 2015-05-27:
I think that is the perfect solution - the one-time-password pre-configured for that particular user.

As far as one-time password generation goes, we should make it memorable. Also, we probably don't need too many bits, as this is only valid for a couple of minutes.

Say we have a list of 256 most common English nouns and 256 most common English Verbs, we can make a 24-bit strong random password
  Dog whistles cardboard.
  Church jumps shark.
  Bulldozer sees poem.
... whatever :) Point is, that it is easy to remember on the way back from the door to your laptop (easier than X72Yt6).

(additional constraint: the sum of any three words should not be longer than what we can display)

( https://xkpasswd.net/s/ )

hzeller, 2015-06-19:
Any progress on this ?

kevinjos, 2015-07-18:
The basic structure is in place, tests are needed. Please see the [branch](https://github.com/kevinjos/rfid-access-control/tree/webinterface) for details and review.

hzeller, 2015-07-22:
Cool! I'll have a look this evening. Are you at NB tonight, maybe I stop by there ?

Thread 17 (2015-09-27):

Increase ShowDoorbell Duration

robbintt, 2015-09-27:
I keep missing the doorbell, any disadvantages to bumping this to 75 seconds?

https://github.com/hzeller/rfid-access-control/blob/master/software/earl/uicontrolhandler.go#L34

hzeller, 2015-09-27:
Should be fine, please send a pull request.
Once we actually have the door open sensor, we can use that to know when to stop the time.

Closed 2015-09-27.

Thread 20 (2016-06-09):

Stop ringing doorbell for each expired / unknown card

patrickod, 2016-06-09:
Currently it appears the bell rings each time someone presents a card that has expired. We should instead provide feedback to the user and leave the doorbell alone, as it's bothersome in the space.

hzeller, 2016-06-10:
mmh, but the intention is that the swipe of the card does the next best thing: ring the doorbell to get in. Probably the problem might be that they anyway do that right after that incident, so that we have too many doorbell rings per time-unit ?

Feedback is given to the user by the blue LED.

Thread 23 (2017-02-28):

Earl runs out of threads is a tty does not connect

hzeller, 2017-02-28:
We had the case that the elevator gate was disconnected for a couple of days after which earl started to act up (it didn't run the external doorbell wav-player anymore). Also the downstairs gate was randomly disconnecting and reconnecting (initially thought to be a cabling problem, but in retrospect could've had the same reason - it didn't happen after a manual fix).

Turns out that it ran out of threads (earl was using > 1500 idling threads at that point). I suspect that the connect attempt/disconnect of the unused serial interface was causing the issues (I didn't check if we also ran out of file-descriptors which would be a strong lead). I remember there was some thing that I wanted to check with the serial terminal implementation we are using (because I had seen issues like that during development), but never did.

So might worthwhile investigating.

Manual fix for now: don't list the non-used tty in the /etc/init.d/earl until we re-connect.

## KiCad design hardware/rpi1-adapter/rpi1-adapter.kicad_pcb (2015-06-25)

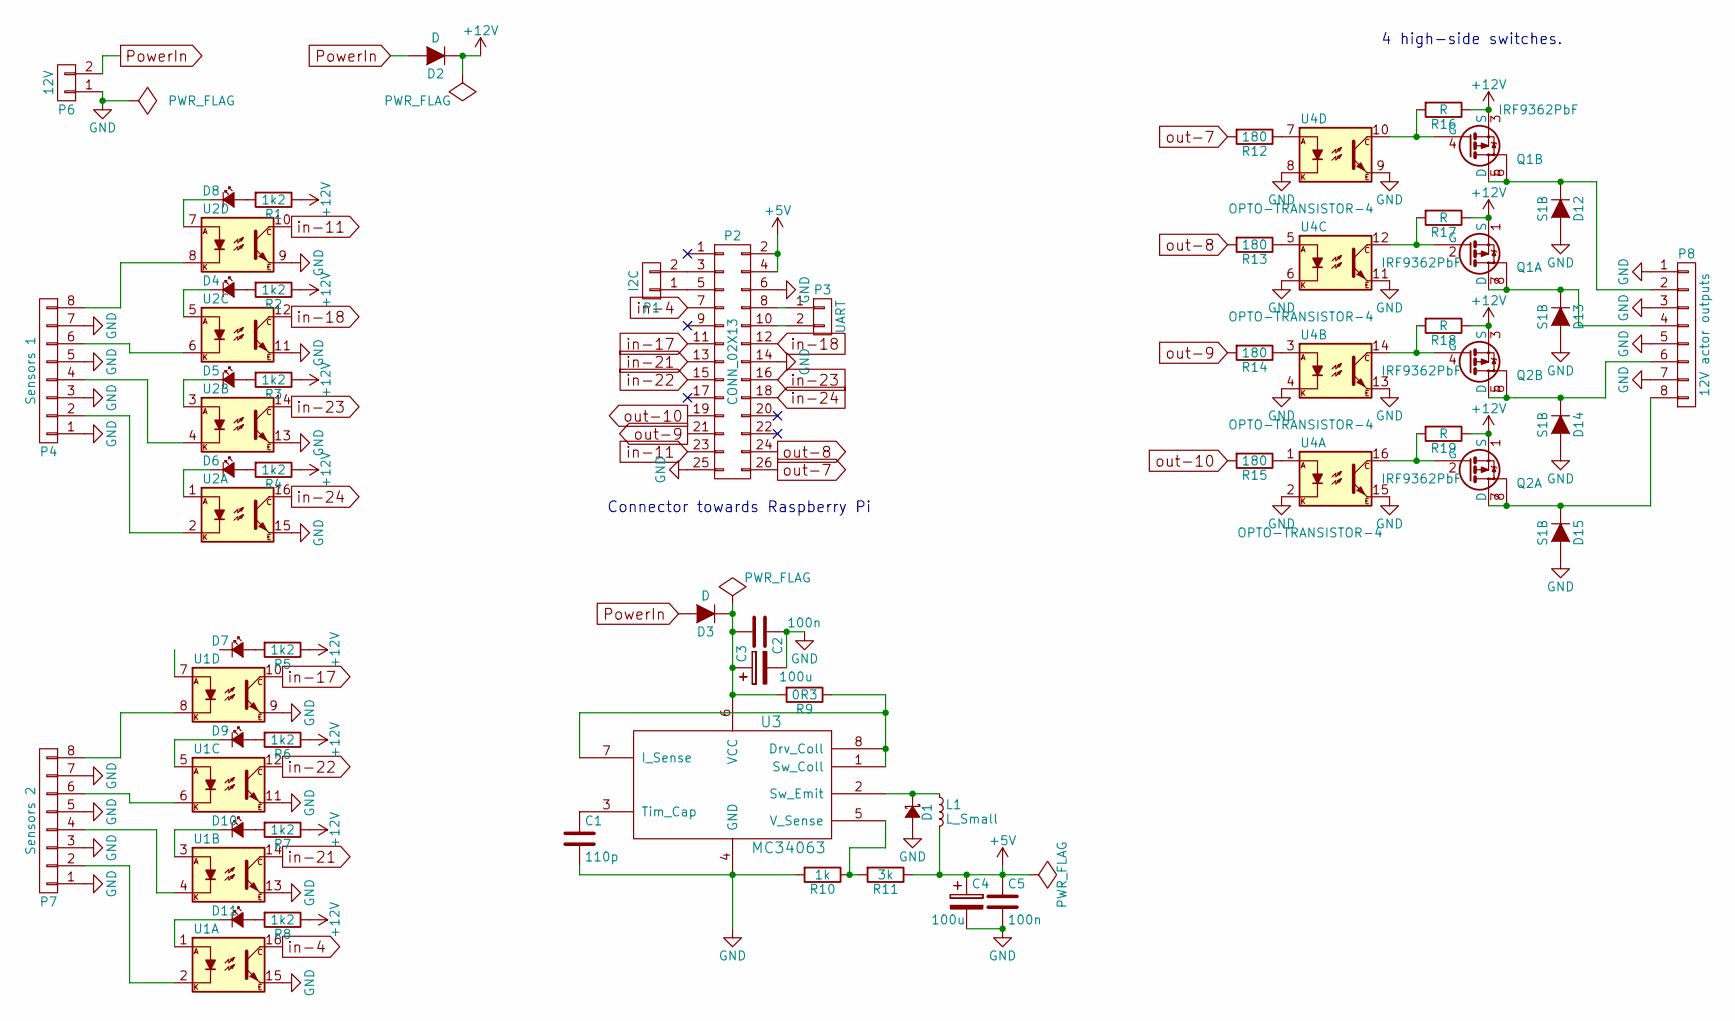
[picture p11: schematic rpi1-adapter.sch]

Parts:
C1: 110p; C_0805_HandSoldering
C2, C5: 100n; C_0805_HandSoldering
C3: 100u; C_Radial_D10_L16_P5
C4: 100u; C_1206_HandSoldering
D1: D_Schottky_Small; Diode-SMA_Handsoldering
D2, D3: D; Diode_DO-35_SOD27_Horizontal_RM10
D4, D5, D6, D7, D8, D9, D10, D11: Led_Small; LED-0805
D12, D13, D14, D15: S1B; Diode-SMA_Standard
L1: L_Small; INDUCTOR_V
P1: I2C; Pin_Header_Straight_1x02
P2: CONN_02X13; Pin_Header_Straight_2x13
P3: UART; Pin_Header_Straight_1x02
P4: Sensors 1; TerminalBlock-8pin-3.5mm
P6: 12V; JACK_ALIM
P7: Sensors 2; TerminalBlock-8pin-3.5mm
P8: 12V actor outputs; TerminalBlock-8pin-3.5mm
Q1, Q2: IRF9362PbF; SO-8
R1, R2, R3, R5, R6, R7, R8: 1k2; R_0805_HandSoldering
R4: 1k2; R_0805
R9: 0R3; R_0805_HandSoldering
R10: 1k; R_0805_HandSoldering
R11: 3k; R_0805_HandSoldering
R12, R13, R14, R15: 180; R_0805_HandSoldering
R16, R17, R18, R19: R; R_0805_HandSoldering
U1, U2, U4: OPTO-TRANSISTOR-4; DIP-16_W7.62mm_LongPads
U3: MC34063; SOIC-8_3.9x4.9mm_Pitch1.27mm

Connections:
+5V: C4.1, C5.1, L1.2, P2.2, P2.4, R11.1
+12V: D2.1 (K), Q1.1 (S), Q1.3 (S), Q2.1 (S), Q2.3 (S), R1.1, R2.1, R3.1, R4.1, R5.1, R6.1, R7.1, R8.1, R16.1, R17.1, R18.1, R19.1
GND: C1.2, C2.1, C3.2, C4.2, C5.2, D1.2 (A), D12.2 (A), D13.2 (A), D14.2 (A), D15.2 (A), P2.6, P2.14, P2.25, P4.1, P4.3, P4.5, P4.7, P6.1, P7.1, P7.3, P7.5, P7.7, P8.1, P8.3, P8.5, P8.7, R10.2, U1.9, U1.11, U1.13, U1.15, U2.9, U2.11, U2.13, U2.15, U3.4 (GND), U4.2, U4.4, U4.6, U4.8, U4.9, U4.11, U4.13, U4.15
unnamed: C1.1, U3.3 (Tim_Cap)
unnamed: C2.2, C3.1, D3.1 (K), R9.2, U3.6 (VCC)
unnamed: D1.1 (K), L1.1, U3.2 (Sw_Emit)
unnamed: D4.1 (K), U2.5
unnamed: D4.2 (A), R2.2
unnamed: D5.1 (K), U2.3
unnamed: D5.2 (A), R3.2
unnamed: D6.1 (K), U2.1
unnamed: D6.2 (A), R4.2
unnamed: D7.2 (A), R5.2
unnamed: D8.1 (K), U2.7
unnamed: D8.2 (A), R1.2
unnamed: D9.1 (K), U1.5
unnamed: D9.2 (A), R6.2
unnamed: D10.1 (K), U1.3
unnamed: D10.2 (A), R7.2
unnamed: D11.1 (K), U1.1
unnamed: D11.2 (A), R8.2
unnamed: D12.1 (K), P8.2, Q1.5 (D), Q1.6
unnamed: D13.1 (K), P8.4, Q1.7 (D), Q1.8
unnamed: D14.1 (K), P8.6, Q2.5 (D), Q2.6
unnamed: D15.1 (K), P8.8, Q2.7 (D), Q2.8
unnamed: P1.1, P2.5
unnamed: P1.2, P2.3
unnamed: P2.8, P3.1
unnamed: P2.10, P3.2
unnamed: P4.2, U2.2
unnamed: P4.4, U2.4
unnamed: P4.6, U2.6
unnamed: P4.8, U2.8
unnamed: P7.2, U1.2
unnamed: P7.4, U1.4
unnamed: P7.6, U1.6
unnamed: P7.8, U1.8
unnamed: Q1.2 (G), R17.2, U4.12
unnamed: Q1.4 (G), R16.2, U4.10
unnamed: Q2.2 (G), R19.2, U4.16
unnamed: Q2.4 (G), R18.2, U4.14
unnamed: R9.1, U3.1 (Sw_Coll), U3.7 (I_Sense), U3.8 (Drv_Coll)
unnamed: R10.1, R11.2, U3.5 (V_Sense)
unnamed: R12.1, U4.7
unnamed: R13.1, U4.5
unnamed: R14.1, U4.3
unnamed: R15.1, U4.1
PowerIn: D2.2 (A), D3.2 (A), P6.2
in-4: P2.7, U1.16
in-11: P2.23, U2.10
in-17: P2.11, U1.10
in-18: P2.12, U2.12
in-21: P2.13, U1.14
in-22: P2.15, U1.12
in-23: P2.16, U2.14
in-24: P2.18, U2.16
out-7: P2.26, R12.2
out-8: P2.24, R13.2
out-9: P2.21, R14.2
out-10: P2.19, R15.2

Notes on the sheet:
Connector towards Raspberry Pi
4 high-side switches.

Board: 2 copper layers, 53 parts (0 on the bottom side), 60 nets, no tracks yet.

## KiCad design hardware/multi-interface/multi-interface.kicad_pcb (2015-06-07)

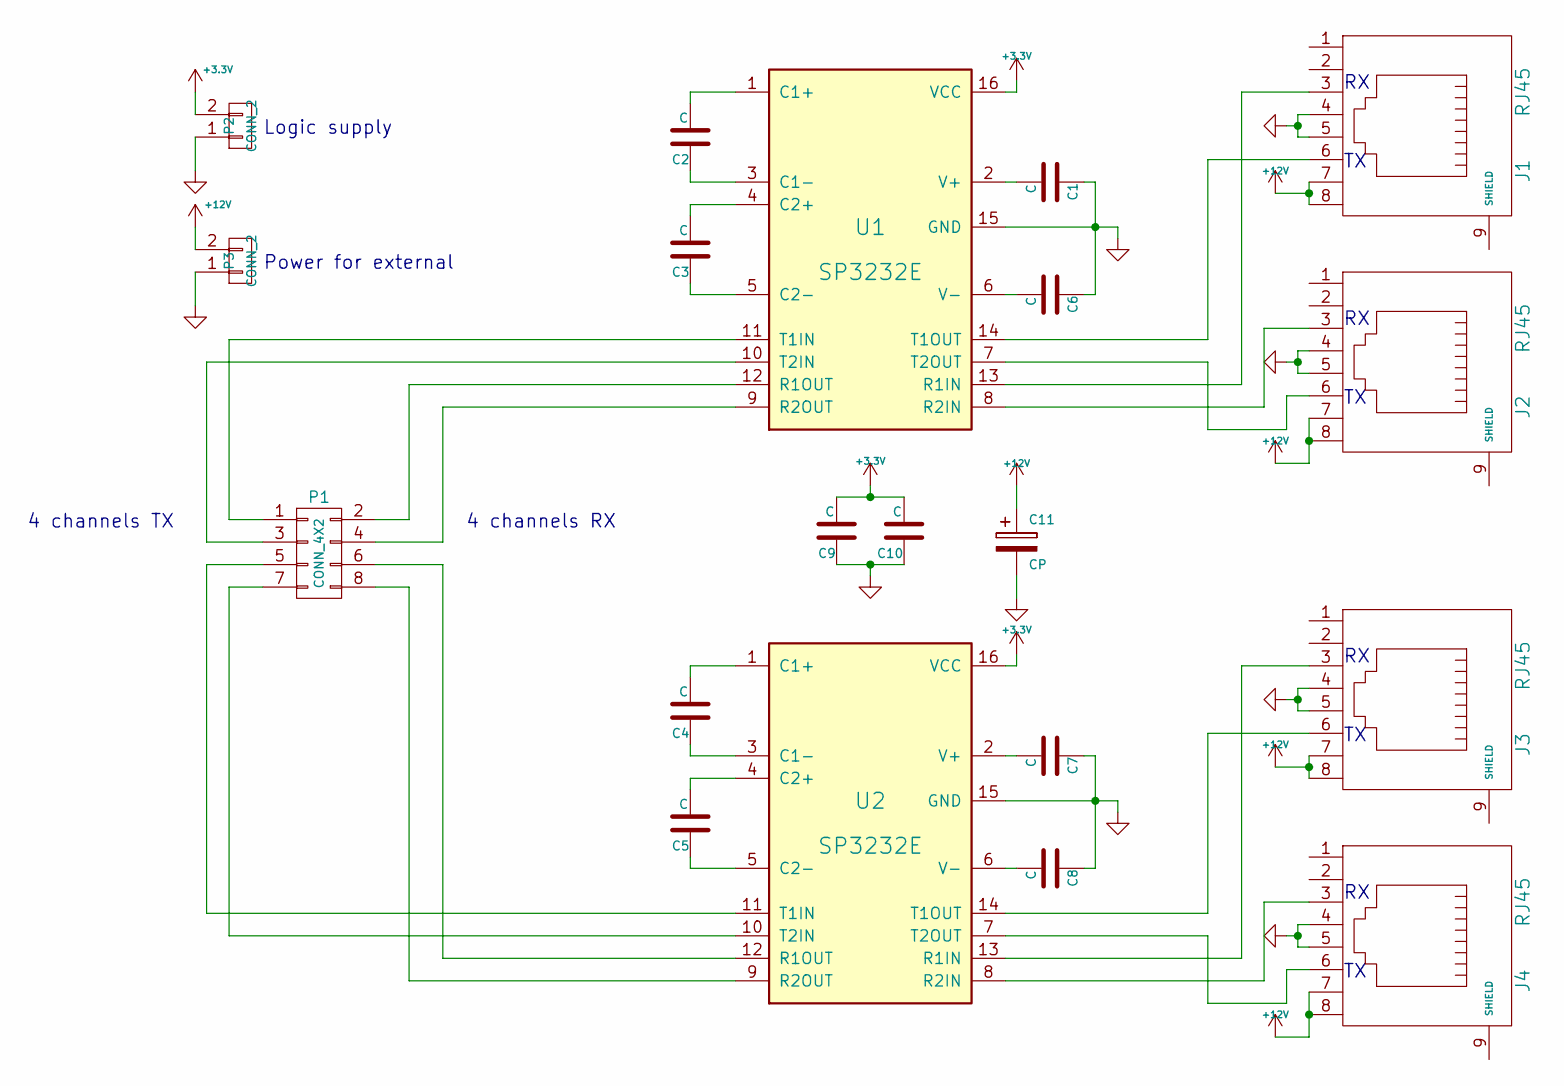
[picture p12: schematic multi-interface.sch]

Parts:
C1, C2, C3, C4, C5, C6, C7, C8, C9, C10: C; SMD-0805
C11: CP; Elko_vert_DM6-3_RM2-5
J1, J2, J3, J4: RJ45; RJ45_8
P1: CONN_4X2; Pin_Header_Straight_2x04
P2, P3: CONN_2; SIL-2
U1, U2: SP3232E; TSSOP-16

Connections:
+3V3: C9.2, C10.2, P2.2, U1.16 (VCC), U2.16 (VCC)
+12V: C11.1, J1.7, J1.8, J2.7, J2.8, J3.7, J3.8, J4.7, J4.8, P3.2
GND: C1.1, C6.1, C7.1, C8.1, C9.1, C10.1, C11.2, J1.4, J1.5, J2.4, J2.5, J3.4, J3.5, J4.4, J4.5, P2.1, P3.1, U1.15 (GND), U2.15 (GND)
unnamed: C1.2, U1.2 (V+)
unnamed: C2.1, U1.3 (C1-)
unnamed: C2.2, U1.1 (C1+)
unnamed: C3.1, U1.5 (C2-)
unnamed: C3.2, U1.4 (C2+)
unnamed: C4.1, U2.3 (C1-)
unnamed: C4.2, U2.1 (C1+)
unnamed: C5.1, U2.5 (C2-)
unnamed: C5.2, U2.4 (C2+)
unnamed: C6.2, U1.6 (V-)
unnamed: C7.2, U2.2 (V+)
unnamed: C8.2, U2.6 (V-)
unnamed: J1.3, U1.13 (R1IN)
unnamed: J1.6, U1.14 (T1OUT)
unnamed: J2.3, U1.8 (R2IN)
unnamed: J2.6, U1.7 (T2OUT)
unnamed: J3.3, U2.13 (R1IN)
unnamed: J3.6, U2.14 (T1OUT)
unnamed: J4.3, U2.8 (R2IN)
unnamed: J4.6, U2.7 (T2OUT)
unnamed: P1.1, U1.11 (T1IN)
unnamed: P1.2, U1.12 (R1OUT)
unnamed: P1.3, U1.10 (T2IN)
unnamed: P1.4, U1.9 (R2OUT)
unnamed: P1.5, U2.11 (T1IN)
unnamed: P1.6, U2.12 (R1OUT)
unnamed: P1.7, U2.10 (T2IN)
unnamed: P1.8, U2.9 (R2OUT)

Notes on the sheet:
4 channels RX
4 channels TX
Logic supply
Power for external

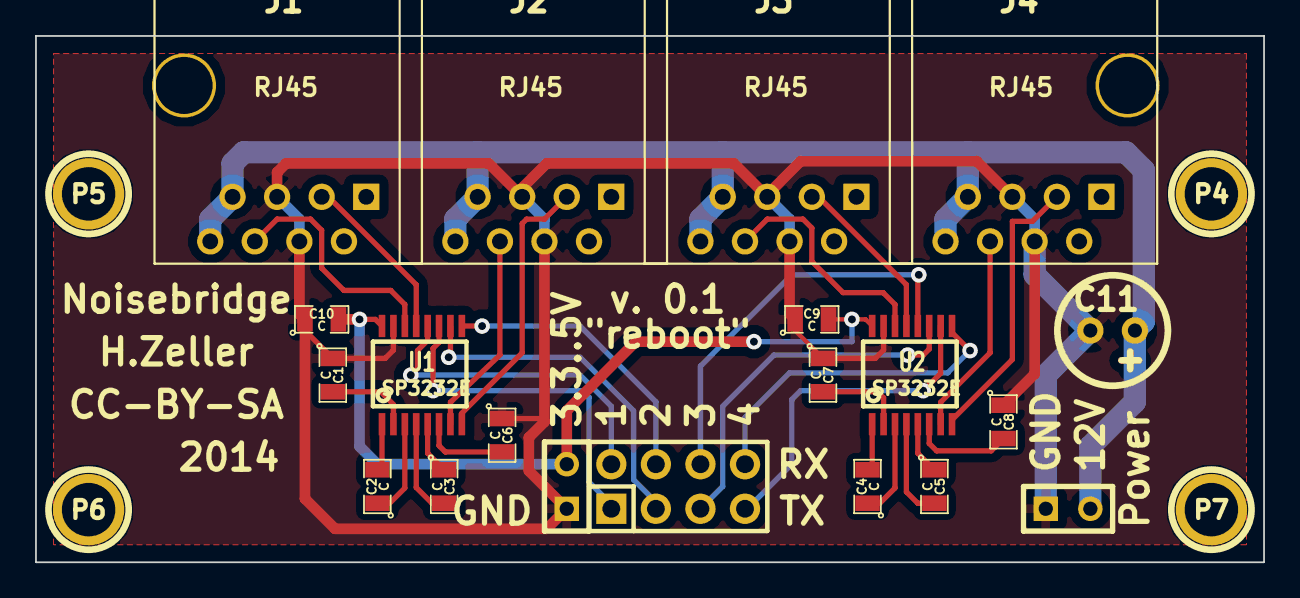
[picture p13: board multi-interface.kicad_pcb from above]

Board: 2 copper layers, 70.0 x 30.0 mm, 24 parts (0 on the bottom side), 31 nets.

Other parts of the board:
P4, P5, P6, P7: CONN_1; 1pin

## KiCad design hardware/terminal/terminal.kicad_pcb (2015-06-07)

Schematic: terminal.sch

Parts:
C1, C2, C3, C4, C5, C6, C9: C; c_0805
C7, C8: CP; Elko_vert_DM5_RM2-5
IC1: ATMEGA8-P; DIP-28__300
J1: RJ45; RJ45_8
P1: Prog; SIL-5
P2: RC522; SIL-8
P3: LCD; Pin_Header_Straight_2x08
P4: Keypad; Pin_Header_Straight_2x08
P5, P6, P7, P8: CONN_1; 1pin
P9: CONN_2X2; Pin_Header_Straight_2x02
P10, P12: CONN_4; SIL-4
P11, P14: CONN_5X2; Pin_Header_Straight_2x05
P13: CONN_3X2; Pin_Header_Straight_2x03
R1, R5: 2.2k; SMD-0805
R2: 2.2k; SM0805
R3, R4: 82; SM0805
R6: 3k; SMD-0805
R7: 12; SMD-0805
U2: SP3232E; TSSOP-16
U3: 7803; LM78XXV

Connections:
+3V3: C5.1, C6.1, C8.1, C9.1, IC1.7 (VCC), P2.8, P3.2, R1.1, R2.1, R7.1, U2.10 (T2IN), U2.16 (VCC), U3.VO
+12V: C7.1, J1.7, J1.8, P10.4, U3.VI
/CS-RFID: IC1.16 ((~SS~/OC1B)PB2), P2.1, R1.2
/RST-RFID: IC1.15 ((OC1A)PB1), P2.7
GND: C3.1, C4.1, C5.2, C6.2, C7.2, C8.2, C9.2, IC1.8 (GND), J1.4, J1.5, J1.9 (SHIELD), P1.1, P2.6, P3.1, P3.5, P3.16, P4.2, P4.4, P4.6, P4.8, P4.10, P4.12, P4.14, P4.16, P9.1, P9.3, P10.1, R5.2, U2.8 (R2IN), U2.15 (GND), U3.GND
KCOL-0: IC1.14 ((ICP)PB0), P4.7
KCOL-1: IC1.9 (PB6(XTAL1/TOSC1)), P4.5
KCOL-2: IC1.10 (PB7(XTAL2/TOSC2)), P4.3
KROW-0: IC1.6 ((XCK/T0)PD4), P4.15
KROW-1: IC1.11 ((T1)PD5), P4.13
KROW-2: IC1.12 ((AIN0)PD6), P4.11
KROW-3: IC1.13 ((AIN1)PD7), P4.9
LCD-D0: IC1.23 ((ADC0)PC0), P3.11
LCD-D1: IC1.24 ((ADC1)PC1), P3.12
LCD-D2: IC1.25 ((ADC2)PC2), P3.13
LCD-D3: IC1.26 ((ADC3)PC3), P3.14
LCD-EN: IC1.28 ((ADC5/SCL)PC5), P3.6
LCD-RS: IC1.27 ((ADC4/SDA)PC4), P3.4
LCD-contr: R6.2, U2.7 (T2OUT)
MISO: IC1.18 ((MISO)PB4), P1.3, P2.4
MOSI: IC1.17 ((MOSI/OC2)PB3), P1.4, P2.3
unnamed: C1.1, U2.1 (C1+)
unnamed: C1.2, U2.3 (C1-)
unnamed: C2.1, U2.4 (C2+)
unnamed: C2.2, U2.5 (C2-)
unnamed: C3.2, U2.2 (V+)
unnamed: C4.2, U2.6 (V-)
unnamed: IC1.1 (PC6(~RESET~)), P1.5, R2.2
unnamed: IC1.4 ((INT0)PD2), R3.2
unnamed: IC1.5 ((INT1)PD3), R4.2
unnamed: P3.3, R5.1, R6.1
unnamed: P3.15, R7.2
unnamed: P9.2, R3.1
unnamed: P9.4, R4.1
RX: IC1.2 ((RXD)PD0), U2.12 (R1OUT)
RX-ext: J1.6, P10.3, U2.13 (R1IN)
SCK: IC1.19 ((SCK)PB5), P1.2, P2.2
TX: IC1.3 ((TXD)PD1), U2.11 (T1IN)
TX-ext: J1.3, P10.2, U2.14 (T1OUT)

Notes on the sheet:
Playground Area
Background Light

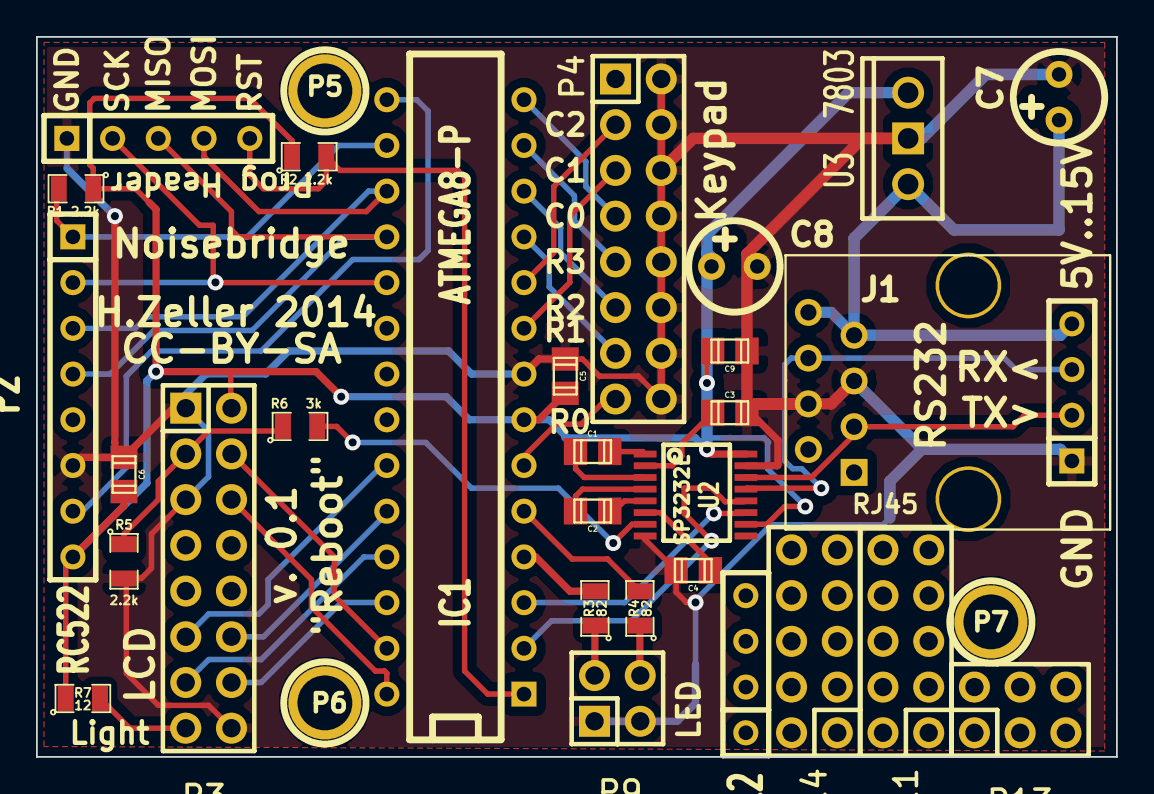
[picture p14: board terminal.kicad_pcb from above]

Board: 2 copper layers, 60.0 x 40.0 mm, 33 parts (0 on the bottom side), 39 nets.

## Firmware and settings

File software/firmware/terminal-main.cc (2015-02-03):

/* -*- mode: c++; c-basic-offset: 2; indent-tabs-mode: nil; -*-
 * Copyright (c) h.zeller@acm.org. GNU public License.
 * TODO: replace all counts of [unsigned] char, [unsigned] short with the
 * appropriate [u]int{8,16}_t. Only strings should deal with 'char'.
 */
#include <avr/eeprom.h>
#include <avr/io.h>
#include <avr/pgmspace.h>
#include <string.h>
#include <util/delay.h>

#include "clock.h"
#include "keypad.h"
#include "lcd.h"
#include "mfrc522/mfrc522.h"
#include "serial-com.h"
#include "tone-gen.h"

#if FEATURE_RFID_DEBUG
#  include "mfrc522-debug.h"
#endif

#define AUX_PORT PORTC
#define AUX_BITS 0x3F

// Pointer to progmem string. Wrapped into separate type to have a type-safe
// way to deal with it.
struct ProgmemPtr {
  explicit ProgmemPtr(const char *d) : data(d) {}
  const char *data;
};
#define _P(s) ProgmemPtr(PSTR((s)))

// TODO: move this repository to noisebridge github.
const char kCodeUrl[] PROGMEM = "https://github.com/hzeller/rfid-access-control";
const char kHeaderText[] PROGMEM = "Noisebridge access terminal |"
  " firmware version git:" GIT_VERSION;

// TODO: make configurable. This represents the layout downstairs.
enum { RED_LED   = 0x20,    // LCD-EN
       GREEN_LED = 0x10,    // LCD-RS
       BLUE_LED  = 0x02 };  // LCD-D5

// Don't change sequence in here. Add stuff at end. This is the
// raw layout in our eeprom which shouldn't change :)
// We store flags in full bytes for convenience reasons.
struct EepromLayout {
  // The first character sometimes seems to be wiped out in power-glitch
  // situations; so let's not store anything of interest here.
  char dummy;

  char name[32];      // Shall be nul terminated. So at most 31 long.
  uint16_t baud_rate; // If garbage, falls back to SERIAL_BAUDRATE
  uint8_t flag_keyboard_tone;  // Use a keyboard tone.
  // other things here.
};

// EEPROM layout with some defaults in case we'd want to prepare eeprom flash.
struct EepromLayout EEMEM ee_data = {
  /* .dummy     = */          0,
  /* .name      = */          "terminal",
  /* .baud_rate = */          SERIAL_BAUDRATE,
  /* .flag_keyboard_tone = */ 1,
};

static char to_hex(unsigned char c) { return c < 0x0a ? c + '0' : c + 'a' - 10; }

// returns value 0x00..0x0f or 0xff for failure.
static unsigned char from_hex(unsigned char c) {
  if (c >= '0' && c <= '9') return c - '0';
  if (c >= 'a' && c <= 'f') return c - 'a' + 10;
  if (c >= 'A' && c <= 'F') return c - 'A' + 10;
  return 0xff;
}

static inline bool isWhitespace(char c) { return c == ' ' || c == '\t'; }

// Like parseHex(), but decimal numbers.
static uint16_t parseDec(const char *buffer) {
  uint16_t result = 0;
  while (isWhitespace(*buffer)) buffer++;
  while (*buffer) {
    unsigned char nibble = from_hex(*buffer++);
    if (nibble > 10)
      break;
    result *= 10;
    result += nibble;
  }
  return result;
}

inline static bool GetFlag(uint8_t* which) { return eeprom_read_byte(which); }
inline static bool SetFlag(uint8_t* which, bool value) {
  eeprom_write_byte(which, value);
  return value;
}

#if FEATURE_BAUD_CHANGE
static uint16_t GetBaudEEPROM() {
  return eeprom_read_word(&ee_data.baud_rate);
}
static void StoreBaudEEPROM(uint16_t bd) {
  return eeprom_write_word(&ee_data.baud_rate, bd);
}
#endif

#ifndef FIXED_TERMINAL_NAME
// Store NUL terminated string in eeprom. But not more than 31+1 bytes.
static void StoreNameEEPROM(const char *name) {
  uint8_t len = strlen(name);
  if (len >= sizeof(ee_data.name)) {
    len = sizeof(ee_data.name) - 1;
  }
  eeprom_write_block(name, &ee_data.name, len);
  for (int i = len; i < (int)sizeof(ee_data.name); ++i) { // Rest NUL bytes.
    eeprom_write_byte((uint8_t*)&ee_data.name + i, '\0');
  }
}
#endif

// Some convenience methods around the serial line.
static void print(SerialCom *out, ProgmemPtr str) {
 char c;
 while ((c = pgm_read_byte(str.data++)) != 0x00)
   out->write(c);
}
static void println(SerialCom *out) {
  print(out, _P("\r\n"));
}
static void println(SerialCom *out, ProgmemPtr str) {
  print(out, str);
  println(out);
}
// Unlike the typically used progmem versions, print buffer from RAM. Named
// obnoxiously so that typically the ProgmemPtr versions are considered.
static void printlnFromRAMPointer(SerialCom *out, const char *str) {
  while (*str) out->write(*str++);
  println(out);
}
#ifndef FIXED_TERMINAL_NAME
static void printlnFromEEPROM(SerialCom *out, void *eeprom_ptr,
                              uint8_t remaining) {
  const uint8_t *ptr = (uint8_t*) eeprom_ptr;
  char c;
  while (remaining-- && (c = eeprom_read_byte(ptr++))) {
    if (c == 0xff) break;   // Uninitialized EEPROM looks like this.
    out->write(c);
  }
  println(out);
}
#endif

static void printHexByte(SerialCom *out, unsigned char c) {
  out->write(to_hex(c >> 4));
  out->write(to_hex(c & 0x0f));
}
static void printHexShort(SerialCom *out, unsigned short s) {
  printHexByte(out, (s >> 8));
  printHexByte(out, (s & 0xff));
}

// A line buffer wrapping around the serial read. Nonblocking fills until either
// the buffer is full or newline reached.
// TODO: actually do clipping and not return the overlong line.
class LineBuffer {
public:
  LineBuffer() : pos_(buffer_) { }

  // Empties serial input buffer and stores in internal buffer.
  // Returns number of characters if newline reached or buffer full.
  // Returns '0' while this condition is not yet reached.
  byte ReadlineNoblock(SerialCom *comm) {
    const char *end_buf = buffer_ + sizeof(buffer_) - 1;
    bool newline_seen = false;
    while (!newline_seen && comm->read_available() && pos_ < end_buf) {
      const char c = (*pos_++ = comm->read());
      newline_seen = (c == '\r' || c == '\n');
    }
    *pos_ = '\0';  // We always have at least one byte space.
    if (newline_seen) *--pos_ = '\0';  // Don't return newline.
    if (newline_seen || pos_ >= end_buf) {
      byte len = pos_ - buffer_;
      pos_ = buffer_;
      return len;
    } else {
      return 0;
    }
  }

  // Returns current line, '\0' terminated, newline stripped.
  const char *line() const { return buffer_; }

private:
  char buffer_[32 + 1];
  char *pos_;
};

static void PrintShortHeader(SerialCom *out) {
  print(out, _P("# "));
  println(out, ProgmemPtr(kHeaderText));
  print(out, _P("# "));
  println(out, ProgmemPtr(kCodeUrl));
}

static void SendHelp(SerialCom *out) {
  PrintShortHeader(out);
  print(out,
        _P("# [Sends]\r\n"
           "#\tI<num-bytes-hex> <uid-hex-str> RFID in range.\r\n"
           "#\tK<char>\tPressed keypad char 0..9, '*','#'\r\n"
           "#\r\n"
           "# [Commands]\r\n"
           "# Lower case: read state\r\n"
           "#\t?\tThis help\r\n"
           "#\tn\tGet persistent name.\r\n"
#if FEATURE_RFID_DEBUG
           "#\tr\tShow MFRC522 registers.\r\n"
#endif
           "#\ts\tShow stats.\r\n"
           "#\te<msg>\tEcho back msg (testing)\r\n"
           "#\r\n"
           "# Upper case: modify state\r\n"
#if FEATURE_LCD
           // We either support the LCD or the LED on that port
           "#\tM<n><msg> Write msg on LCD-line n=0,1.\r\n"
#else
           "#\tL[<R|G|B>] Set (combination of) LED Red/Green/Blue.\r\n"
#endif
           "#\tT<L|H>[<ms>] Low or High tone for given time (default 250ms).\r\n"
           "#\tF<K><1|0> Set flag. 'K'=Keypad click.\r\n"
           "#\tR\tReset RFID reader.\r\n"
#ifndef FIXED_TERMINAL_NAME
           "#\tN<name> Set persistent name of this terminal. Send twice.\r\n"
#endif
#if FEATURE_BAUD_CHANGE
           "#\tB<baud> Set baud rate. Persists if current rate confirmed.\r\n"
#endif
           ));
  println(out, _P("? ok"));
}

static void SendStats(SerialCom *out, unsigned short cmd_count) {
  print(out, _P("s commands-seen=0x"));
  printHexShort(out, cmd_count);
  print(out, _P("; dropped-rx-bytes=0x"));
  printHexShort(out, out->dropped_rx());
  print(out, _P("\r\n"));
}

#ifndef FIXED_TERMINAL_NAME
// We require to send the same name twice in consecutive commands to make
// sure to not set the name due to accidents or random line noise.
static uint8_t first_name_write_command_count = 0x42;
static uint8_t name_checksum;
static void ReceiveName(SerialCom *com,
                        const char *line, uint8_t command_count) {
  uint8_t checksum = 0;
  const char *cs_run = line;
  for (uint8_t i = 0; *cs_run; ++i, ++cs_run) {
    checksum ^= *cs_run + i;  // crude, but should catch typos.
  }
  if (cs_run - line < 4) {
    // Make sure that we don't run into random line-noise
    println(com, _P("Name too short!"));
    return;
  }
  if (first_name_write_command_count + 1 == command_count) {
    // The previous command was name setting as well. See if we got the same.
    if (checksum == name_checksum) {
      StoreNameEEPROM(line + 1);
      print(com, _P("Name stored: "));
      printlnFromEEPROM(com, &ee_data.name, sizeof(ee_data.name));
    } else {
      println(com, _P("Name mismatch!"));
    }
  } else {
    first_name_write_command_count = command_count;
    name_checksum = checksum;
    println(com, _P("Name received. Send 2nd time to confirm."));
  }
}
#endif
static void PrintTerminalName(SerialCom *com) {
#ifdef FIXED_TERMINAL_NAME
  println(com, _P(FIXED_TERMINAL_NAME));
#else
  printlnFromEEPROM(com, &ee_data.name, sizeof(ee_data.name));
#endif
}

static void OutputTone(SerialCom *com, const char *line) {
  uint16_t duration = parseDec(line + 2);
  if (duration == 0) duration = 250;
  if (line[1] == 'H' || line[1] == 'h') {
    ToneGen::Tone(ToneGen::hz_to_divider(1200), Clock::ms_to_cycles(duration));
  } else {
    ToneGen::Tone(ToneGen::hz_to_divider(300), Clock::ms_to_cycles(duration));
  }
  println(com, _P("T ok"));
}

#if not FEATURE_LCD
static void ResetLED() {
  PORTC |= RED_LED|GREEN_LED|BLUE_LED;
}
static void SetLED(SerialCom *com, const char *line) {
  ResetLED();
  for (const char *color = line+1; *color ; color++) {
    switch (*color) {
    case 'R': case 'r': PORTC &= ~RED_LED; break;
    case 'G': case 'g': PORTC &= ~GREEN_LED; break;
    case 'B': case 'b': PORTC &= ~BLUE_LED; break;
    }
  }
  println(com, _P("L ok"));
}
#endif

static void SetFlagCommand(SerialCom *com, const char *line) {
  bool result;
  switch (line[1]) {
  case 'K':  // Keyboard click
    result = SetFlag(&ee_data.flag_keyboard_tone, line[2] == '1');
    break;
  default:   // Any other character or end of string.
    println(com, _P("E invalid flag"));
    return;
  }
  println(com, result ? _P("T flag on") : _P("T flag off"));
}

#if FEATURE_BAUD_CHANGE
static void SetNewBaudRate(SerialCom *com, const char *line) {
  const uint16_t bd = parseDec(line + 1);
  if (!SerialCom::IsValidBaud(bd)) {
    println(com, _P("E not a valid baudrate between 300..38400"));
    return;
  }
  if (bd == com->baud()) {
    // We are already running at that speed. Obviously communication works.
    // Safe to store permanently.
    StoreBaudEEPROM(bd);
    println(com, _P("Baud rate stored in EEPROM"));
  } else {
    println(com, _P("Baud rate will be switched after this line. Send command "
                    "a second time to permanently store in EEPROM"));
    com->SetBaud(bd);
  }
}
#endif

static void SendUid(const MFRC522::Uid &uid, SerialCom *out) {
  if (uid.size > 15) return;  // fishy.
  out->write('I');
  printHexByte(out, (unsigned char) uid.size);
  out->write(' ');
  for (int i = 0; i < uid.size; ++i) {
    printHexByte(out, uid.uidByte[i]);
  }
  println(out);
}

static void SendKeypadCharIfAvailable(char keypad_char, SerialCom *out) {
  if (!keypad_char) return;
  out->write('K');
  out->write(keypad_char);
  println(out);
  if (GetFlag(&ee_data.flag_keyboard_tone)) {
    ToneGen::Tone(ToneGen::hz_to_divider(1000), Clock::ms_to_cycles(30));
  }
}

int main() {
  DDRC = AUX_BITS;

#if not FEATURE_LCD
  ResetLED();
#endif

  _delay_ms(100);  // Wait for voltage to settle before we reset the 522

  Clock::init();

  ToneGen::Init();
  KeyPad keypad;

#if FEATURE_LCD
  LcdDisplay lcd(24);
#endif

  MFRC522 card_reader;
  card_reader.PCD_Init();

  SerialCom comm;
#if FEATURE_BAUD_CHANGE
  comm.SetBaud(GetBaudEEPROM());
#endif

  PrintShortHeader(&comm);
  println(&comm, _P("# Type '?<RETURN>' for help."));
  print(&comm, _P("# Name: "));
  PrintTerminalName(&comm);

  LineBuffer lineBuffer;
  MFRC522::Uid last_sent_uid;

  unsigned short commands_seen_stat = 0;
  enum RfidState {
    RFID_IDLE,
    RFID_FIRST_SEEN,
    RFID_REPEAT_1,
    RFID_REPEAT_2,
  } state = RFID_IDLE;
  for (;;) {
    // See if there is a command incoming.
    char line_len;
    if ((line_len = lineBuffer.ReadlineNoblock(&comm)) != 0) {
      ++commands_seen_stat;
      const char command = lineBuffer.line()[0];
      switch (command) {
      case '?':
        SendHelp(&comm);
        break;
        // Commands that modify stuff. Upper case letters.
      case 'R':
        card_reader.PCD_Reset();
        card_reader.PCD_Init();
        last_sent_uid.size = 0;
        println(&comm, _P("Reset RFID reader."));
        break;
#if FEATURE_LCD
      case 'M':
        if (line_len >= 2 && lineBuffer.line()[1] - '0' < 2) {
          lcd.print(lineBuffer.line()[1] - '0', lineBuffer.line() + 2);
          println(&comm, _P("M ok"));
        } else {
          println(&comm, _P("E row number must be 0 or 1"));
        }
        break;
#else
      case 'L':
        SetLED(&comm, lineBuffer.line());
        break;
#endif
#ifndef FIXED_TERMINAL_NAME
      case 'N':
        ReceiveName(&comm, lineBuffer.line(), commands_seen_stat & 0xff);
        break;
#endif
#if FEATURE_BAUD_CHANGE
      case 'B':
        SetNewBaudRate(&comm, lineBuffer.line());
        break;
#endif
      case 'T':
        OutputTone(&comm, lineBuffer.line());
        break;
      case 'F':
        SetFlagCommand(&comm, lineBuffer.line());
        break;
        // Lower case letters don't modify any state.
      case 'e':
        printlnFromRAMPointer(&comm, lineBuffer.line());
        break;
#if FEATURE_RFID_DEBUG
      case 'r':
        showRFIDStatus(&comm, &card_reader);
        break;
#endif
      case 's':
        SendStats(&comm, commands_seen_stat);
        break;
      case 'n':
        comm.write('n');
        PrintTerminalName(&comm);
        break;
      case '\0': // TODO: the lineBuffer sometimes returns empty lines.
        break;
      default:
          print(&comm, _P("E Unknown command "));
          if (command < ' ' || command > 'z') {
            print(&comm, _P("0x"));
            printHexByte(&comm, command);
          } else {  // printable as ASCII
            comm.write('\'');
            comm.write(command);
            comm.write('\'');
          }
          println(&comm, _P("; '?' for help."));
      }
    }

    // While we still have bytes ready to read, handle these first, otherwise
    // we might run out of buffer because the RFID reading takes its sweet time.
    if (comm.read_available())
      continue;

    // --
    // Alright, here is the section where we send stuff unsolicited to the
    // host. Any pressed key or RFID we encounter.
    // --

    SendKeypadCharIfAvailable(keypad.ReadKeypad(), &comm);

    // We only want to send the RFID once when it is brought up to the reader,
    // no repeat. However, if it is removed and brought back to the reader, we
    // want to send the ID again (once). So it is not as simple as just
    // remembering if we just saw the same ID that we sent last time.
    //
    // The RFID reader, while the card is present, will say is-new-card-present,
    // then allows to read the serial number, then will say in the next call
    // that the card is _not_ present. After that, this repeats.
    // So present, !present, present, !present ..
    //
    // We want to get rid of the repeat. Because it alternates, we can't
    // simply count, but need to keep track of this in a little state-machine.
    //  - RFID_IDLE is the idle state,
    //  - RFID_FIRST_SEEN is the interesting one,
    //  - RFID_REPEAT_{1,2} eat the repetition.
    bool cp = card_reader.PICC_IsNewCardPresent();
    bool is_same = true;
    if (cp) {
      if (card_reader.PICC_ReadCardSerial()) {
        is_same = (last_sent_uid.size == card_reader.uid.size
                   && memcmp(last_sent_uid.uidByte, card_reader.uid.uidByte,
                             last_sent_uid.size) == 0);
      } else {
        cp = false;
      }
    }
    switch (state) {
    case RFID_IDLE:       state = cp ? RFID_FIRST_SEEN : RFID_IDLE; break;
    case RFID_FIRST_SEEN: state = cp ? RFID_FIRST_SEEN : RFID_REPEAT_1; break;
    case RFID_REPEAT_1:   state = cp ? RFID_REPEAT_2 : RFID_IDLE; break;
    case RFID_REPEAT_2:   state = cp ? RFID_FIRST_SEEN : RFID_REPEAT_1; break;
    default: state = RFID_IDLE;  // should never happen.
    }
    if (!is_same || state == RFID_FIRST_SEEN) {
      SendUid(card_reader.uid, &comm);
      last_sent_uid = card_reader.uid;
    }
  }
}

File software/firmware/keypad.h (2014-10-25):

/* -*- mode: c++; c-basic-offset: 2; indent-tabs-mode: nil; -*-
 * Copyright (c) h.zeller@acm.org. GNU public License.
 */

#ifndef AVR_KEYPAD_H_
#define AVR_KEYPAD_H_

#include "clock.h"

// For wiring more like 'pretty' physical layout, logical layout is a mess
// with bits distributed between ports :)
// row 1:PD7 2:PD6 3:PD5 4:PD4  (all port D; conveniently shifted by 4)
// col 1:PB0 2:PB7 3:PB6        (all port B)
class KeyPad {
  enum {
    // We read from Port-D to top 4 bits
    ROW_PORTD_SHIFT = 4,

    // Columns will be outputs on Port-B
    COL_1 = (1<<0),
    COL_2 = (1<<6),
    COL_3 = (1<<7),
    PORTB_OUT_MASK = COL_1 | COL_2 | COL_3,
  };

public:
  KeyPad();

  // This method needs to be called regularly.
  // It returns the current character pressed on the keypad if it settled
  // for long enough (it returns it only once, no auto-repeat).
  // Returns a NUL character ('\0') if no key is pressed.
  char ReadKeypad();

private:
  typedef unsigned char keypad_state_t;
  keypad_state_t SampleCol(unsigned char col_sample_bit,
                           keypad_state_t col_data);
  keypad_state_t readKeypadState();

  keypad_state_t current_state_;
  bool character_returned_;
  Clock::cycle_t start_time_;
};

#endif  // AVR_KEYPAD_H_

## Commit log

2014-08-04 o Add 'reset' command. o Smallify string constants (things started to overwrite). o current state: text data bss dec hex filename 6080 346 0 6426 191a main.elf
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2014-08-05 o Update documentation. o Always send 'E' error responses on error. o Acknowlege M command.
    [terminal-main.cc]
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2014-08-09 o Starting an reader case.
    [rfid-cover.scad, rfid-cover.stl]
2014-08-10 o Simplify case calculation (no rounded corner anymore, just a slope). Faster, since no rotational extrusion (=torus) has to be calculated. o Make smaller for a tight fit. o Better clearance everywhe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
    [rfid-cover.scad, rfid-cover.stl]
2014-08-10 o slightly shift the internal frame up to not 'cut corners' at the bottom.
    [rfid-cover.scad]
2014-08-10 o Add a screw block.
    [rfid-cover.scad]
2014-08-10 o Create countersink screw hole.
    [rfid-cover.scad]
2014-08-10 o Some post-1st-print fiddling.
    [rfid-cover.scad]
2014-08-10 o Add mounting screws.
    [rfid-cover.scad]
2014-08-10 o add pcb holding podests.
    [rfid-cover.scad]
2014-08-10 o solve manifold issue.
    [rfid-cover.scad]
2014-08-10 o Make better use of case_fn. Document it.
    [rfid-cover.scad]
2014-08-10 o Logo center tweak. o Readme update. o call mouthful case_and_cleat() -> top_assemmbly()
    [rfid-cover.scad]
2014-08-10 o Add xray view.
    [rfid-cover.scad]
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2014-08-10 o Better naming of cleat related variables.
    [rfid-cover.scad]
2014-08-11 o allow to mount board upside down.
    [rfid-cover.scad]
2014-08-11 o Add way to cut out hole at the top.
    [rfid-cover.scad]
2014-08-11 o allow left and right top cable hole.
    [rfid-cover.scad]
2014-08-11 o Don't limit pcb stakes by clearance.
    [rfid-cover.scad]
2014-08-13 o better podest for board mounting.
    [rfid-cover.scad]
2014-08-14 o Start terminal schematic.
    [terminal.sch]
2014-08-14 o Add programming header.
    [terminal.sch]
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2014-08-15 o Add initial board.
    [terminal.kicad_pcb, terminal.sch]
2014-08-15 o (test; place programming header)
    [terminal.kicad_pcb]
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2014-08-16 Work in progress o more layout work done o use chargepump of remaining rs232 driver to provide negative voltage to display.
    [terminal.kicad_pcb, terminal.sch]
2014-08-17 o add voltage divider LCD contrast.
    [terminal.kicad_pcb, terminal.sch]
2014-08-17 o First complete routing. o Add voltage divider to get a proper negative voltage for LCD.
    [terminal.kicad_pcb, terminal.sch]
2014-08-17 o Move programming header inwards a bit so that it doesn't collicde with chrystal
    [terminal.kicad_pcb]
2014-08-17 o Add 'playground' area.
    [terminal.kicad_pcb, terminal.sch]
2014-08-17 o better voltage divider LCD contrast.
    [terminal.sch]
2014-08-17 o input voltage label refined.
    [terminal.kicad_pcb]
2014-08-17 o Add background light option. o Better labeling on both sides of the board.
    [terminal.kicad_pcb, terminal.sch]
2014-08-17 o Wider tracks for power.
    [terminal.kicad_pcb]
2014-08-17 o Make DRC happy: it wanted an explicit track between two pads even though they were already connected. Ah well.
    [terminal.kicad_pcb]
2014-08-17 o Add option for input filter cap.
    [terminal.kicad_pcb, terminal.sch]
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2014-08-17 o Adding a logo is a freakin' nightmare in KiCAD. So just added text attribution to Noisebridge and author.
    [terminal.kicad_pcb]
2014-08-17 o slightly move voltage label.
    [terminal.kicad_pcb]
2014-08-17 o Add version 0.1 "reboot" o add some default trace widths.
    [terminal.kicad_pcb]
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2014-08-17 o connect 7 and 8 to 12V. o Better labelling RX/TX on board.
    [terminal.kicad_pcb, terminal.sch]
2014-08-17 o anothe de-coupling capacitor close to the SP3232E can't harm.
    [terminal.kicad_pcb, terminal.sch]
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2014-08-18 o Initial version multi RJ45 interface.
    [multi-interface.kicad_pcb, multi-interface.sch]
2014-08-18 o final touches - ground plane - reference to Noisebridge and git repository.
    [multi-interface.kicad_pcb]
2014-08-18 o move mounting hole P6... out of the way. o Add version and 'reboot' designator :)
    [multi-interface.kicad_pcb]
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2014-08-18 o standard output formats.
    [terminal.kicad_pcb]
2014-08-18 o make 12v powertrace slightly wider.
    [multi-interface.kicad_pcb]
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2014-08-28 o little better checksum to detect swapped letters. o Update documentation: checklist how to set up a new terminal.
    [terminal-main.cc]
2014-09-03 o sandwich turned out a bit thicker.
    [rfid-cover.scad]
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2014-09-05 Add parseArg() function to separate device name from baudrate. Also run 'go fmt' to fix formatting.
2014-09-15 Add authenticator framework, fix reading bug
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2014-10-27 o Smallish cleanup: replace if/else/else with switch/case
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2014-11-02 o Add baseplate design files.
    [standoffs.scad]
2014-11-03 o add RPi standoff.
    [standoffs.scad]
2014-11-03 o Add side-holder for serial acrylic plate
    [side-holder.scad]
2014-11-05 o Both plates are the same width, so make the holder for it a bit wider. Let's see if the overhang is managed properly by the printer.
    [side-holder.scad]
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2014-11-06 o pre-drill needs to be a bit larger.
    [side-holder.scad]
2014-11-10 o make side-holder with step.
    [side-holder.scad]
2014-11-10 o Add LED display holder.
    [controller-box.scad, side-holder.scad]
2014-11-12 o Adapt side-holder to manual holes ...
    [side-holder.scad]
2014-11-12 o if the manual drilled holes don't fit the print, make the print fit the holes ...
    [side-holder.scad]
2014-11-15 o Adapt a bit to real-world conditions :)
    [side-holder.scad]
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2014-12-23 o Prevent SD card from falling out.
    [standoffs.scad]
2015-01-24 o Classify authentication result from simple 'bool' to a set of available status codes (in other languages, one would call this 'enumeration'). o Use this to give user feedback - a failed authenticat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
2015-01-25 o Move case/ -> terminal-case/
    [rfid-cover.scad]
2015-01-26 o Adapt cover to house a LED.
    [rfid-cover.scad]
2015-01-28 o Enable brown-out fuse (yeah, was disabled all the time :/) o Skip first byte in EEPROM, as this seems to be most vulnerable in power-glitch situations.
    [terminal-main.cc]
2015-01-28 Power outage with corrupted terminal re-connect reminded to do the following: o Less logging on connect unless it is clear that we handle the terminal o Exponential backoff when reconnecting to broke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
2015-02-02 o Separate out height of LED/screwblock to print a slightly higher box. o add way to separately print the logo for dual extrusion logo inlay.
    [rfid-cover.scad]
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2015-02-12 o Rate limit door-strike opening relay (in particular: don't interfere with ourselve just opening).
2015-03-04 Remove whitespace from VERSION string
    the ARM linker doesn't like it :(
2015-06-06 o Re-connect with current KiCad library. o add cache to repository to make sure this is kept.
    [multi-interface.kicad_pcb, multi-interface.sch]
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2015-06-06 o Get terminal up-to-date with current KiCad libraries o check in cache as it is vital to be backward compatible.
    [terminal.kicad_pcb, terminal.sch]
2015-06-07 o correct some paths to find the 3D components.
    [multi-interface.kicad_pcb]
2015-06-07 o More adaption of current paths for 3D shapes.
    [terminal.kicad_pcb]
2015-06-07 o properly turn the 3D model of TSSOP 16 o Update rendered image
    [multi-interface.kicad_pcb]
2015-06-15 o Start RPi adapter with 8 OptoCoupler inputs and 4 outputs.
    [rpi1-adapter.kicad_pcb, rpi1-adapter.sch]
2015-06-16 o more on adapter. Add DC/DC converter to only need one 12V supply.
    [rpi1-adapter.kicad_pcb, rpi1-adapter.sch]
2015-06-16 o Make screw terminal solder pads more beefy.
    [rpi1-adapter.kicad_pcb]
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2018-11-15 No network stall on pegasus doorbell (#33)
    * Make doorbell ring request to pegasus timeout gracefully not hang.
    With recent network issues, we encountered that Earl run into trouble.
    Possibly because it couldn't reach pegasus and was patiently waiting
    for doorbell requests to come back, while exhausting local threads.
2018-12-29 Add CircleCI build (#36)
    * Add CircleCI build (Automatically build x86 and arm binaries.)
    * Fix version build
2018-12-30 README.md typo: fix link to case image (#34)
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

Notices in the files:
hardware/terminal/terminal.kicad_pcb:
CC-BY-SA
